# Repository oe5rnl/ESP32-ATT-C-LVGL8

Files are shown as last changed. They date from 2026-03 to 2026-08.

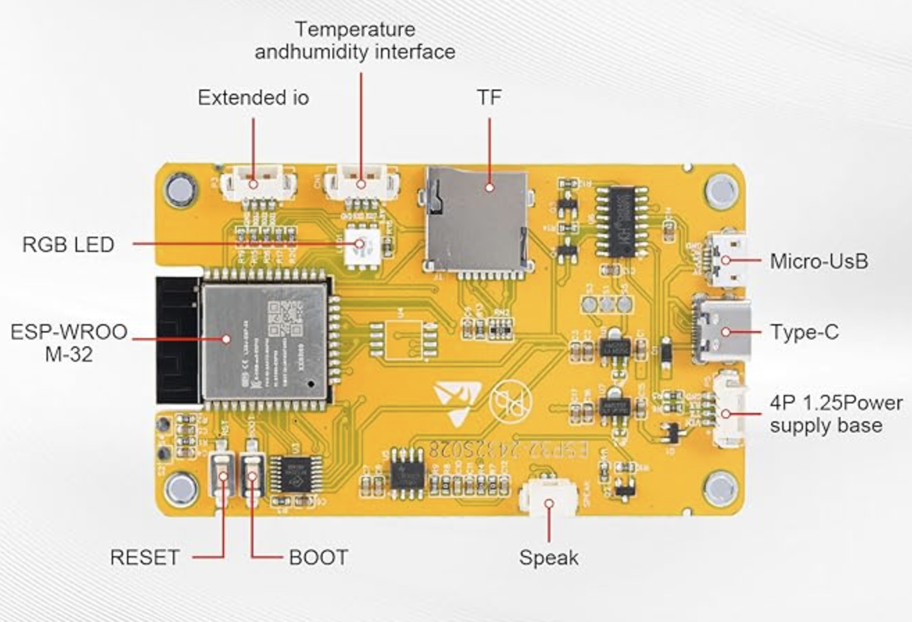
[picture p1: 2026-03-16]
esp32/docu/esp32-display/2-Specification/Board-hinten.png

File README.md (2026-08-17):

# Attenuator Controller

Das Projekt realisiert einen Controller für RF-Attenuators (HF-Dämpfungsglieder).

Es besteht aus einer Basisplatine und den optionalen Bendienelementen:  
* Ein ESP32 CYD Touch-Display  
* Ein 2.8" OLED Display  
* Einen Drehgeber mit Druckschalter  

Der Betrieb kann in folgenden Varianten erfolgen. Basisplatine **und**:  
* Nur ESP Touch Display
* OLED Display und Drehgeber
* ESP Touch Display und oder/und OLED sowie oder/und Drehgeber 

### Firmware installieren (ohne Installation)

Für Endnutzer gibt es im Ordner [install/](install/) einen Offline-Flasher, der
ohne PlatformIO oder Python auskommt — es wird nur ein mitgeliefertes Programm
aufgerufen. Details siehe [install/README.md](install/README.md).

- **ESP32:** Board per USB anstecken und `flash-esp32.sh` (Linux) bzw.
  `flash-esp32.bat` (Windows) ausführen. Der serielle Port wird automatisch
  erkannt; das eigenständige `esptool` ist bereits enthalten.
- **Pico:** **BOOTSEL** gedrückt halten, einstecken und `firmware/firmware.uf2`
  auf das Laufwerk `RPI-RP2` kopieren — ganz ohne Zusatzprogramm.

> **Hinweis:** Die auslieferbaren Firmware-Dateien werden vom Entwickler einmalig
> per [install/export.sh](install/export.sh) erzeugt (baut ESP32 + Pico und legt
> `firmware-merged.bin` sowie `firmware.uf2` in `install/firmware/` ab).

---

## Systemübersicht

ESP32 CYD (Touch-Display 320×240, WebGUI via WiFi, LVGL 8 UI) kommuniziert über
UART (115200 Baud) mit dem Raspberry Pi Pico (Drehgeber, SSD1306 OLED). Beide
steuern gemeinsam die Attenuator-Relais.

Verdrahtung

Der am häufigsten Abzutreffende Attenuatos ist die 135dB Variante.  
Siehe dazu zur Verkabelung ATT_135db.md  
Test der EinzelRelais mit dem Testmenü am Display und auf der Webseite.

### ESP32 — Touch-Controller

LVGL-8-Steuerungsoberfläche auf ESP32 CYD (Cheap Yellow Display):

- 2.8" Touch-Display ILI9341 (320×240), Variante CYD2USB mit ST7789
- WLAN: AP-Modus und Client-Modus gleichzeitig
- WebGUI mit identischer Funktion wie das Touch-Display
- NVS-Persistenz (Wert, Presets, WiFi-Modus, Set-Modus)
- FreeRTOS Dual-Core: LVGL/UI auf Core 1, WebSocket/WiFi auf Core 0
- Kommunikation mit dem Pico über UART0

### Pico — Relais-/Drehgeber-Controller

Raspberry Pi Pico als Attenuator-Controller:

- Drehgeber zur Auswahl und Aktivierung von Dämpfungswerten
- Optionales SSD1306 OLED-Display (I2C)
- Automatische Attenuator-Erkennung über ADC (Spannungsteiler an GP26 / ADC0)
- Bis zu 8 bistabile Relais (H-Brücke oder Einzel-Pin)
- Serielle Steuerung über UART vom ESP32

---

## Unterstützte Attenuatoren

Quelle: [pico/src/Attenuator.cpp](pico/src/Attenuator.cpp),
[pico/src/att_types.h](pico/src/att_types.h) und die jeweiligen `att_*`-Klassen.

| Typ | Max. dB | Schritte | Relay-Modus | Status im Code |
|-----|---:|---:|---|---|
| R&S 26.5 GHz | 110 dB | 10 dB | Static (Einzelpin) | implementiert (`Att26GHz`) |
| R&S RS-135 dB | 135 dB | 5 dB | Bridge (H-Brücke) | implementiert (`Att135dB`) |
| RS-141 dB | (variable Pads) | — | Bridge (H-Brücke) | implementiert (`Att141dB`) |
| Typ B | — | — | — | **nicht** implementiert (`AttB` → „NOT IMPLEMENTED") |

### Automatische Erkennung über ADC (GP26 / ADC0)

**Maßgeblich ist der Code** in [pico/src/main.cpp](pico/src/main.cpp) (`getAttenuator()`):

| Spannung (v) | Erkannter Attenuator |
|---|---|
| 0.0 V ≤ v < 0.7 V | RS-141 dB |
| 0.9 V ≤ v < 1.5 V | 26.5 GHz |
| 1.7 V ≤ v < 2.3 V | Typ B |
| 2.4 V ≤ v ≤ 3.3 V | RS-135 dB |
| außerhalb aller Fenster | **NOT IMPLEMENTED** — kein Attenuator, kein GPIO wird gesetzt |

> **Hinweis:** Die alten READMEs und der Kommentar in
> [pico/src/att_types.h](pico/src/att_types.h) nennen eine andere Zuordnung
> (0.0–0.8 V → 26.5 GHz usw.). Diese stimmt **nicht** mit dem aktuellen Code
> überein. Ungültige Spannungen (Lücken 0.7–0.9 / 1.5–1.7 / 2.3–2.4 V sowie alles
> außerhalb) liefern `getAttenuator()` = `-1`; `create_attenuator()` gibt dann
> `nullptr` zurück, es wird **kein GPIO** aktiviert und das Display zeigt
> „NOT IMPLEMENTED".

### Widerstände für den Spannungsteiler

R10 nach 3,3 V, R11 nach GND (an Pico ADC):

```
 3,3V
  |
 R10
  |---- Pico ADC (GP26)
  |
 R11
  |
 GND
```

| Attenuator | R10 | R11 |
|---|-----|-----|
| 26.5 GHz | offen | offen |
| RS-141 dB | 3k3 | 4k7 |
| Typ B | 4k7 | 3k3 |
| RS-135 dB | 0 Ohm | offen |

> **ACHTUNG:** Niemals zwei 0-Ohm-Widerstände einbauen — das kurzschließt den
> 3,3-V-Ausgang des Pico.
>
> **ACHTUNG:** Vor dem Verbinden des Attenuators mit der Steuerplatine am Display
> prüfen, ob der gewünschte Attenuator angezeigt wird. Wird `ATTENUATOR_26_5GHz`
> eingestellt, aber ein Attenuator mit H-Brücken-Ansteuerung verwendet, kann es
> zur Zerstörung der Relais führen.

---

## Hardware

### Pico — GPIO-Belegung

| Pin | GPIO | Funktion |
|-----|---|---|
| 1  | GP0  | TX → ESP32 (Serial1) |
| 2  | GP1  | RX ← ESP32 (Serial1) |
| 4  | GP2  | Relais 1a |
| 5  | GP3  | Relais 1b |
| 6  | GP4  | I2C SDA (Display) |
| 7  | GP5  | I2C SCL (Display) |
| 9  | GP6  | Relais 2a |
| 10 | GP7  | Relais 2b |
| 11 | GP8  | Relais 3a |
| 12 | GP9  | Relais 3b |
| 14 | GP10 | Relais 4a |
| 15 | GP11 | Relais 4b |
| 16 | GP12 | Relais 5a |
| 17 | GP13 | Relais 5b |
| 19 | GP14 | Relais 6a |
| 20 | GP15 | Relais 6b |
| 21 | GP16 | Relais 7a |
| 22 | GP17 | Relais 7a |
| 24 | GP18 | Relais 8a |
| 25 | GP19 | Encoder SW |
| 26 | GP20 | Encoder DT (B) | 
| 27 | GP21 | Encoder CLK (A) |
| 29 | GP22 | Relais 8b |
| 31 | GP26 | ADC0 — Attenuator-Erkennung |
| 32 | GP27 | Relais 9a |
| 34 | GP28 | Relais 9b |

#### Relais-Mapping RS-135 dB (bistabil, ON/OFF-Pin-Paare)

Quelle: [pico/src/att_135db.h](pico/src/att_135db.h) / [.cpp](pico/src/att_135db.cpp).

| Relais | ON-Pin | OFF-Pin | tatsächlicher Pad-Wert |
|---|---|---|---|
| U1 (40bB A) | GP3 | GP2 | 40 dB |
| U2 (20dB A) | GP7 | GP6 | 20 dB |
| U3 (5 dB) | GP9 | GP8 | 5 dB |
| U4 (20dB B) | GP11 | GP10 | 20 dB |
| U5 (10 dB) | GP13 | GP12 | 10 dB |
| U6 (40dB B) | GP15 | GP14 | 40 dB |
| U7 (RF) | GP17 | GP16 | RF ON/OFF |

#### Relais-Mapping 26.5 GHz (Static, HIGH = aktiv)

Quelle: [pico/src/att_26ghz.h](pico/src/att_26ghz.h).

| Pad | GPIO | Pin |
|-----|---|-----|
| 10 dB | GP10 | 14 |
| 20 dB | GP11 | 15 |
| 40 dB (A) | GP12 | 16 |
| 40 dB (B) | GP13 | 17 |

---

## WiFi-Konfiguration

### WiFi-Credentials einstellen

Erstelle `esp32/src/wifi_credentials.h` mit deinen WLAN-Zugangsdaten (Vorlage:
[esp32/src/wifi_credentials.h.example](esp32/src/wifi_credentials.h.example)):

Der AP ist unabhängig von der Datei stets erreichbar. Die Client-Anbindung ans Heimnetz kann man jederzeit zur Laufzeit über die WebGUII (WLAN-Suche → Verbinden) oder das Display setzen — die Werte landen im NVS. wifi_credentials.h ist nur praktisch, wenn man die Zugangsdaten schon beim Kompilieren fest hinterlegen will (z. B. damit sich das Gerät ohne manuelle Ersteinrichtung direkt verbindet).

```cpp
#pragma once
#define WIFI_SSID     "DeinSSID"
#define WIFI_PASSWORD "DeinPasswort"
```

Diese Datei ist in [.gitignore](.gitignore) und wird nicht committet.

### WiFi-Modi

Quelle: [esp32/src/webserver.h](esp32/src/webserver.h) (`apply_wifi_mode()`).

Es gibt genau **zwei** Modi; jeder von 0 verschiedene Wert wird intern auf `2`
gesetzt. Die Einstellung wird im NVS (`wmode`) gespeichert.

- **Modus 0 (Aus):** WiFi vollständig deaktiviert (`WIFI_OFF`), Webserver und AP
  werden gestoppt, mDNS beendet.
- **Modus 2 (AP + Client):** Der Access Point ist **immer** aktiv. Ein
  Client (STA) wird zusätzlich nur gestartet, wenn gültige Client-Zugangsdaten
  vorliegen — andernfalls läuft das Gerät im AP-only-Betrieb.
  - AP-SSID: `ESP32-ATT`
  - AP-Passwort: `12345678` (Standardwert — bitte ändern)
  - AP-IP: `192.168.4.1`
  - Client-Zugangsdaten stammen aus dem NVS (`wifi_ssid` / `wifi_pass`),
    vorbelegt aus [esp32/src/wifi_credentials.h](esp32/src/wifi_credentials.h);
    zur Laufzeit über das Display-Menü (**Menu → WLAN**) bzw. die WLAN-Suche der
    WebGUI setzbar.
  - Die Client-Verbindung erfolgt nicht blockierend; nach Timeout (ca. 20 s) oder
    bei Fehler fällt das Gerät automatisch auf AP-only zurück.
  - mDNS (`esp32-att.local`) wird erst nach erfolgreicher Client-Verbindung
    aktiviert.

### WebGUI

Nach dem Start erreichbar unter:
- **AP-Modus:** `http://192.168.4.1`
- **Client-Modus:** `http://esp32-att.local` (oder die angezeigte IP)

---

## Quick Start

### ESP32 flashen
```bash
cd esp32
./upload.sh
# oder manuell:
~/.platformio/penv/bin/pio run -t upload
~/.platformio/penv/bin/pio device monitor
# CYD2USB-Variante (ST7789):
~/.platformio/penv/bin/pio run -e cyd2usb -t upload
```

### Pico flashen
```bash
cd pico
./upload_main.sh
# oder manuell:
~/.platformio/penv/bin/pio run -t upload
~/.platformio/penv/bin/pio device monitor
```

> **Tipp:** Falls `pio: command not found` erscheint, den vollen Pfad
> `~/.platformio/penv/bin/pio` verwenden oder PlatformIO global installieren.

**Voraussetzungen:** [PlatformIO](https://platformio.org/) (CLI oder VS-Code-Extension).

### Tools einrichten

1. **Repository holen**
   ```bash
   git clone <REPO-URL>
   cd ESP32-ATT-C-LVGL8
   ```

2. **PlatformIO installieren** — eine der beiden Varianten:
   - **VS Code + Extension (empfohlen):** [VS Code](https://code.visualstudio.com/)
     installieren, dann die Extension **PlatformIO IDE** hinzufügen. Build/Upload
     erfolgen über die PlatformIO-Toolbar.
   - **CLI (Kommandozeile):**
     ```bash
     python3 -m pip install --user platformio
     # oder das offizielle Installskript:
     # curl -fsSL https://raw.githubusercontent.com/platformio/platformio-core-installer/master/get-platformio.py | python3
     ```
     Danach steht `pio` unter `~/.platformio/penv/bin/pio` zur Verfügung
     (ggf. in den `PATH` aufnehmen).

3. **Toolchains & Bibliotheken** — werden beim ersten `pio run` automatisch
   geladen (Platforms `espressif32` und `raspberrypi`, Frameworks und alle
   `lib_deps` aus den jeweiligen [platformio.ini](esp32/platformio.ini)).
   Eine manuelle Installation ist nicht nötig.

4. **Serielle Rechte (Linux):** Für Upload/Monitor den eigenen Benutzer zur
   Gruppe `dialout` hinzufügen und neu anmelden:
   ```bash
   sudo usermod -aG dialout $USER
   ```

5. **WLAN-Zugangsdaten (optional):** Nur nötig, wenn die Client-Zugangsdaten
   bereits beim Kompilieren fest hinterlegt werden sollen — siehe Abschnitt
   „WiFi-Credentials einstellen". Ohne diese Datei ist der Access Point trotzdem
   erreichbar; die Client-Anbindung lässt sich zur Laufzeit über WebGUI/Display
   setzen.

---

## Serielles Kommunikationsprotokoll (UART, 115200 Baud)

Alle Nachrichten sind ASCII-Zeilen, abgeschlossen mit `\n`.

### Pico → ESP32

**Startup-Info** (einmalig nach Pico-Reset):

| Befehl | Beschreibung |
|---|---|
| `RELAYS:<n>` | Anzahl der Relais |
| `ATTNAME:<name>` | Attenuator-Name |
| `STEP:<n>` | Schrittweite in dB |
| `MAXDB:<n>` | Maximalwert in dB |
| `RELMODE:<n>` | Relay-Modus: `0`=Bridge, `1`=Static |
| `RFSWITCH:<n>` | RF-Schalter vorhanden: `0`/`1` |
| `PICOVER:<ver>` | Pico-Firmware-Version |

**Laufzeit:**

| Befehl | Beschreibung |
|---|---|
| `<n>dB` | Aktueller Dämpfungswert (Display-Sync) |
| `SEL<n>` | Ausgewählte Stelle: `0`=Hunderter, `1`=Zehner, `2`=Einer |
| `SETMODE:<n>` | Set-Modus: `0`=Direct, `1`=Time, `2`=Button |
| `RF:<n>` | RF-Schalter-Zustand: `0`/`1` |
| `TESTSTATE:<i>,<s>` | Test: Relais-Index `i`, Zustand `s` (`0`/`1`) |
| `SETOK` | Pico hat im Set-Button-Modus angewendet |

### ESP32 → Pico

| Befehl | Beschreibung |
|---|---|
| `<n>dB` | Dämpfung Display-Sync (kein Schalten) |
| `SET:<n>dB` | Dämpfung sofort schalten (Relais) |
| `TIMED:<n>dB` | Zeitgesteuert schalten |
| `SEL<n>` | Aktive Stelle ändern |
| `SETMODE:<n>` | Set-Modus umschalten |
| `RF:<n>` | RF-Schalter setzen: `0`/`1` |
| `TEST:START` | Relay-Test starten |
| `TEST:SEL:<i>` | Test-Relais `i` auswählen |
| `TEST:ACTION` | Test: Puls/Toggle am gewählten Relais |
| `TEST:END` | Test beenden |

---

## Implementierungsdetails ESP32

| Core | Aufgaben |
|---|---|
| **Core 0** | WiFi-Stack, AsyncTCP, ESPAsyncWebServer, WebSocket-Callbacks |
| **Core 1** | `setup()` / `loop()`, LVGL `lv_timer_handler()`, UART-Empfang |

Kommunikation zwischen den Cores über FreeRTOS-Queue (`xQueueSend` / `xQueueReceive`).

---

## Projektstruktur

```
ESP32-ATT-C-LVGL8/
├── shared/
│   └── version.h               # Versionsnummern ESP32 + Pico (0.51)
├── esp32/
│   ├── platformio.ini          # PlatformIO + TFT_eSPI Build-Flags
│   ├── lv_conf.h               # LVGL-8-Konfiguration
│   └── src/
│       ├── main.cpp            # LVGL UI, UART-Kommunikation
│       ├── webserver.h         # AsyncWebServer, WebSocket, HTML
│       ├── wifi_credentials.h  # WLAN-Zugangsdaten (nicht im Repo)
│       └── lv_font_digits_72.c # Custom 72 px Ziffern-Font
├── pico/
│   └── src/
│       ├── main.cpp            # Hauptprogramm, UART, Encoder, ADC-Erkennung
│       ├── Attenuator.h/.cpp   # Abstrakte Basisklasse + Factory
│       ├── att_26ghz.h/.cpp    # R&S 26.5 GHz (Static, 110 dB / 10 dB)
│       ├── att_135db.h/.cpp    # R&S 135 dB (Bridge, 135 dB / 5 dB)
│       ├── att_141db.h/.cpp    # RS-141 dB (Bridge)
│       ├── att_b.h/.cpp        # Typ B (nicht implementiert)
│       ├── att_types.h         # Typ-Konstanten + ADC-Grenzwerte (Kommentar veraltet)
│       ├── test.h/.cpp         # Relay-Testmodus
│       ├── SSD1306.h/.cpp      # OLED-Display-Treiber
│       ├── big_digits.h        # Große Ziffern für OLED
│       ├── font.h              # OLED-Font
│       └── toggle_gpio10_13.cpp # Standalone-GPIO-Testhilfe
├── Schaltung/                  # KiCad Schaltplan + PCB
├── install/                    # Offline-Flasher (esptool + Skripte, ohne Installation)
└── docs/                       # Zusätzliche Dokumentation
```

---

## Lizenz

MIT — siehe [LICENSE](LICENSE).

Ausnahme: Der Ordner [esp32/docu/esp32-display/](esp32/docu/esp32-display/)
enthält Hersteller-Dokumentation (Sunton) und ist **nicht** von der MIT-Lizenz
abgedeckt.

Build by OE5RNL & OE5NVL & Chatgpt & Claude

### Haftungsausschluss

Diese Hard- und Software wird „wie besehen" ohne jegliche Gewährleistung
bereitgestellt — weder ausdrücklich noch stillschweigend, insbesondere keine
Gewährleistung der Marktgängigkeit oder Eignung für einen bestimmten Zweck.
Die Nutzung erfolgt auf eigene Gefahr. Die Autoren übernehmen keine Haftung für
Schäden jeglicher Art (z. B. an Attenuatoren, Relais, Messgeräten oder sonstiger
Ausrüstung), die aus dem Aufbau, dem Betrieb oder der Nutzung dieses Projekts
entstehen.

Insbesondere kann eine falsche Attenuator-Erkennung oder fehlerhafte Verdrahtung
zur Zerstörung der Relais oder des angeschlossenen Dämpfungsglieds führen (siehe
Warnhinweise im Abschnitt „Widerstände für den Spannungsteiler"). Vor dem
Anschluss stets prüfen, ob der korrekte Attenuator angezeigt wird.

## Basiert auf

[ESP32-Cheap-Yellow-Display](https://github.com/witnessmenow/ESP32-Cheap-Yellow-Display)
— LVGL8-Beispiel.

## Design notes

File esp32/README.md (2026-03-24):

# ESP32 - 26.5 GHz Attenuator Controller

LVGL 8 Steuerungsoberfläche für ESP32 CYD (Cheap Yellow Display) mit Touch-Display und WebGUI.

## Features

- **3-Tab-Menü** (Main, Defaults, Config) mit Tab-Leiste am unteren Rand
- **Main-Tab:** 3-stellige Ziffernanzeige (72px Custom Font), einzeln anwählbar per Touch mit Unterstrich-Cursor. UP/Down/Set-Buttons ändern die ausgewählte Stelle
- **Defaults-Tab:** 6 vordefinierte dB-Werte als Buttons (2 Reihen × 3). Kurzer Klick übernimmt den Wert, langer Klick öffnet ein Nummernfeld zum Editieren
- **Config-Tab:** Autoenter-Switch (ein/aus), WLAN-Modus (Aus / AP / Client)
- **Ziffernbegrenzung:** Maximalwert und aktivierbare Stellen über `#define` konfigurierbar (`DIGIT_MAX_VAL`, `DIGIT_MAX_0/1/2`)
- **Persistente Speicherung:** Ziffernwert, Default-Button-Werte, Autoenter und WiFi-Modus werden im ESP32 NVS gespeichert und überleben Stromausfall/Neustart
- **Webinterface:** Steuerung über Browser (WiFi AP oder Client-Modus)
- **Set-Button:** Wird nur angezeigt wenn Autoenter ausgeschaltet ist

## Hardware

- **Board:** ESP32-2432S028 (Cheap Yellow Display / CYD)
- **Display:** ILI9341, 320×240, RGB565, SPI
- **Touch:** XPT2046 auf separatem VSPI-Bus
- **Variante CYD2USB:** ST7789-Treiber (Environment `cyd2usb`)
- **Attenuator GPIOs** (active LOW):
  - GPIO 4: 10 dB Pad
  - GPIO 16: 20 dB Pad
  - GPIO 17: 40 dB Pad A
  - GPIO 35: 40 dB Pad B
- **UART für Pico** (am P3 Stecker):
  - GPIO 21: TX → Pico GP1 (Serial1 RX)
  - GPIO 22: RX ← Pico GP0 (Serial1 TX)

## Voraussetzungen

- [PlatformIO](https://platformio.org/) (CLI oder VS Code Extension)
- ESP32-2432S028 Board (CYD)

## Build & Flash

```bash
# Standard CYD (ILI9341)
~/.platformio/penv/bin/pio run -t upload

# CYD2USB Variante (ST7789)
~/.platformio/penv/bin/pio run -e cyd2usb -t upload

# Seriellen Monitor öffnen
~/.platformio/penv/bin/pio device monitor  -p /dev/ttyUSB0
```

> **Tipp:** Falls `pio: command not found` erscheint, verwende den vollen Pfad `~/.platformio/penv/bin/pio` oder installiere PlatformIO global.

## WiFi-Konfiguration

### WiFi-Credentials einstellen

Erstelle `src/wifi_credentials.h` mit deinen WLAN-Zugangsdaten:

```cpp
#pragma once
#define WIFI_SSID "DeinSSID"
#define WIFI_PASSWORD "DeinPasswort"
```

Diese Datei ist in `.gitignore` und wird nicht committed.

### WiFi-Modi

- **Modus 0 (Aus):** WiFi deaktiviert
- **Modus 1 (AP):** Access Point Modus
  - SSID: `ESP32-ATT`
  - Passwort: `12345678`
  - IP: `192.168.4.1`
- **Modus 2 (Client):** Verbindet sich mit deinem WLAN
  - Läuft parallel zum AP für durchgehende Erreichbarkeit
  - Verwendete Zugangsdaten: Aus Config-Tab oder `wifi_credentials.h`
  - mDNS: `esp32-att.local`

## WebGUI

Nach dem Start ist das WebInterface erreichbar unter:
- **AP-Modus:** http://192.168.4.1
- **Client-Modus:** http://esp32-att.local (oder die angezeigte IP)

Das WebGUI bietet die gleichen Funktionen wie das Touch-Display:
- Dämpfungswert einstellen (UP/DOWN oder direkte Eingabe)
- Default-Werte verwalten
- Auto-Set ein/aus
- WLAN-Netzwerke scannen und verbinden (im AP-Modus)

## Projektstruktur

```
esp32/
├── platformio.ini          # PlatformIO Konfiguration mit TFT_eSPI Build-Flags
├── lv_conf.h               # LVGL 8 Konfiguration (Montserrat 24/48 aktiviert)
├── src/
│   ├── main.cpp            # Hauptprogramm mit LVGL GUI
│   ├── webserver.h         # AsyncWebServer + WebSocket
│   ├── wifi_credentials.h  # WiFi-Zugangsdaten (git-ignored)
│   └── lv_font_digits_72.c # Custom 72px Ziffern-Font
└── README.md               # Diese Datei
```

## Anpassungen

### Maximalwerte ändern

In `src/main.cpp`:

```cpp
#define DIGIT_MAX_VAL  110   /* maximaler Gesamtwert in dB             */
#define DIGIT_MAX_0      1   /* Hunderter: 0 .. DIGIT_MAX_0           */
#define DIGIT_MAX_1      9   /* Zehner:    0 .. DIGIT_MAX_1           */
#define DIGIT_MAX_2      0   /* Einer:     0 = nicht wählbar (10er-Schritte) */
```

### Default-Werte ändern

In `src/main.cpp`:

```cpp
int32_t default_values[6] = {20, 40, 60, 10, 30, 50};
```

## Lizenz

Siehe [LICENSE](../LICENSE) im Root-Verzeichnis.

## Credits

Basiert auf dem LVGL8 Beispiel von [ESP32-Cheap-Yellow-Display](https://github.com/witnessmenow/ESP32-Cheap-Yellow-Display).

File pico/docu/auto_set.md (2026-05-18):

# Auto-Set Funktion

## Grundidee

Auto-Set steuert, ob eine Änderung des dB-Werts *sofort* an die Relais
weitergegeben wird oder erst nach einem expliziten Bestätigungsschritt.

---

## ESP32

**Zustand:** `bool autoset`  
Standard: `true`, persistent in NVS via `prefs.putBool("ae", autoset)`

### Auto-Set ON
- Jeder Druck auf UP/DOWN (`btn_up_cb` / `btn_down_cb`) ruft sofort
  `apply_attenuation()` auf → Relais schalten unmittelbar
- Der „SET"-Button ist **versteckt** (`LV_OBJ_FLAG_HIDDEN`)
- Digit-Klick im Haupttab löst ebenfalls sofort `apply_attenuation()` aus

### Auto-Set OFF
- UP/DOWN ändert nur den angezeigten Wert, die Relais schalten **nicht**
- Der „SET"-Button wird **sichtbar** – erst sein Druck ruft
  `apply_attenuation_set()` auf
- Der Wert kann unverbindlich eingestellt und dann per Tastendruck übernommen werden

### Quellen für Zustandsänderungen

| Auslöser | Reaktion |
|---|---|
| Toggle-Switch im Config-Tab (LVGL)| Speichert in NVS, sendet `AUTO:ON/OFF` per Serial an Pico, WebSocket-Broadcast |
| Web-Interface (Browser) | `web_update_ae()` synchronisiert LVGL-Switch + Label + SET-Button, sendet `AUTO:ON/OFF` an Pico |
| Serial-Eingang vom Pico (`AUTO:ON/OFF`) | Aktualisiert `autoset`, NVS, LVGL-Switch, Label, SET-Button |

---

## Pico

**Zustand:** `bool auto_set_mode`  
Standard: `true`

### Auto-Set ON
- Wenn der ESP32 einen dB-Wert schickt (`"XXXdB"`), ruft
  `apply_attenuation_from_esp_db()` auch `apply_relays()` auf → Relais
  schalten sofort mit
- OLED zeigt unten: `AUTO-SET: ON`

### Auto-Set OFF
- `apply_attenuation_from_esp_db()` aktualisiert nur Display und internen
  Zustand, ruft **kein** `apply_relays()` auf
- OLED zeigt unten: `AUTO-SET: OFF`
- Ein **Encoder-Einzelklick** übernimmt den angezeigten Wert manuell auf die
  Relais und sendet ihn zurück an den ESP32

### Quellen für Zustandsänderungen

| Auslöser | Reaktion |
|---|---|
| Serial vom ESP32 (`AUTO:ON/OFF`)  | Setzt `auto_set_mode`, aktualisiert OLED |
| Beim Start | Sendet aktuellen Zustand per `sync_state_to_esp32()` → ESP32 übernimmt ihn |

---

## Synchronisation zwischen ESP32 und Pico

```
ESP32  ──── AUTO:ON / AUTO:OFF ────►  Pico   (Serial1, 115200 Baud)
Pico   ──── AUTO:ON / AUTO:OFF ────►  ESP32  (beim Booten via sync_state_to_esp32)
```

Der Zustand wird in **beide Richtungen** synchronisiert.  
Der ESP32 ist Master für Änderungen aus UI und Web-Interface.  
Der Pico schickt seinen persistierten Zustand beim Start.  
**Letzter Schreiber gewinnt.**

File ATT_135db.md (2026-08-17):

# 135 dB Attenuator – Schaltplan

```
                                                 ╔═════════════════════════
                                                 ║
   135dB Attenuator                              ║   Controller Board
                                                 ║
╔════════════════════╗                           ║
║                    ║                           ║
║                ┌──────────────────────────────────── B1 U1out1 
║   O    40dB    O   ║                           ║
║   └───────────────────────────────────────────────── B1 U1out2
║                    ║                           ║
║                    ║                           ║
║                ┌──────────────────────────────────── B2 U2out1 
║   O    20dB    O   ║                           ║
║   └───────────────────────────────────────────────── B2 U2out2
║                    ║                           ║
║                    ║                           ║
║                ┌──────────────────────────────────── B3 U3out1
║   O     5dB    O   ║                           ║
║   └───────────────────────────────────────────────── B3 U3out2
║                    ║                           ║
║                    ║                           ║
║                ┌──────────────────────────────────── B4 U4out1
║   O    20dB    O   ║                           ║
║   └───────────────────────────────────────────────── B4 U4out2
║                    ║                           ║
║                    ║                           ║
║                ┌──────────────────────────────────── B5 U5out1 
║   O    10dB    O   ║                           ║
║   └───────────────────────────────────────────────── B5 U5out2
║                    ║                           ║
║                    ║                           ║
║                ┌──────────────────────────────────── B6 U6out1 
║     O  40dB    O   ║                           ║
║   └───────────────────────────────────────────────── B6 U6out2
║                    ║                           ║
║                    ║                           ║
║                ┌──────────────────────────────────── B7 U7out1
║   O    RF-SW   O   ║                           ║
║   └───────────────────────────────────────────────── B7 U7out2
║                    ║                           ║
║                    ║                           ║
║                    ║                           ║     B8 U8out1
║                    ║                           ║
║                    ║                           ║     B8 U8out2
║                    ║                           ║
║                    ║                           ║
║                    ║                           ║     B9 U9out1
║                    ║                           ║
╚════════════════════╝                           ║     B9 U9out2
                                                 ║
                                                 ║
                                                 ║
                                                 ╚═════════════════════════
```
Das ist die am häfigsten anzutreffende Version des Abschwächers !!!

Es gibt zwei Versionen von diesem Schater.  
Die Lage der dB Schalter ist bei beiden gleich.  

Beide haben einen RF ON/OFF Schalter.  
Bei der Version A befinden sich die RF-SW Pins direkt neben dem dB Schaltern.  
Bei der Version B besteht ein Abstand zwischen des dB Schaltern und dem RF-Switch.  

Von der Funktionalität sind beide Schalter gleich, nur
der Frequenzgereich ist unterschiedlich.

Der Schalter mit dem Abstand hat Dioden zur Erkennung der Rückleistung  
eigebaut. Diese begrenzen den Frequenzbereich.

Die Funktion der Demodulator-Dioden wird vom Controller nicht unterstützt!

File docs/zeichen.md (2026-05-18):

---

## Box-Drawing Characters – Referenz

### Einfache Linie (Single)
```
┌─────────────────────┐
│  Inhalt             │
├─────────────────────┤
│  Zeile 2            │
└─────────────────────┘
```

### Doppelte Linie (Double)
```
╔═════════════════════╗
║  Inhalt             ║
╠═════════════════════╣
║  Zeile 2            ║
╚═════════════════════╝
```

### Gemischt – Horizontal doppelt / Vertikal einfach
```
╒═════════════════════╕
│  Inhalt             │
╞═════════════════════╡
│  Zeile 2            │
╘═════════════════════╛
```

### Gemischt – Horizontal einfach / Vertikal doppelt
```
╓─────────────────────╖
║  Inhalt             ║
╟─────────────────────╢
║  Zeile 2            ║
╙─────────────────────╜
```

### Zeichen-Übersicht

| Funktion | Einfach | Doppelt |
|---|:---:|:---:|
| Ecke oben links | ┌ | ╔ |
| Ecke oben rechts  | ┐ | ╗ |
| Ecke unten links  | └ | ╚ |
| Ecke unten rechts | ┘ | ╝ |
| Horizontal | ─ | ═ |
| Vertikal | │ | ║ |
| T links | ├ | ╠ |
| T rechts | ┤ | ╣ |
| T oben | ┬ | ╦ |
| T unten | ┴ | ╩ |
| Kreuz | ┼ | ╬ |

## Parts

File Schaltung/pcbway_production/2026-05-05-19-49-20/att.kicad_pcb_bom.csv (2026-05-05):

Designator | Quantity | Value | Footprint | Package | MPN | DNP | Mount_Type | Description | KiLib_Generator
A1 | 1 | RaspberryPi_Pico | RaspberryPi_Pico_SMD |  |  |  | smt | Versatile and inexpensive microcontroller module (with full pinout for test point and debug connections) powered by RP2040 dual-core Arm Cortex-M0+ processor up to 133 MHz, 264kB SRAM, 2MB QSPI flash; also supports Raspberry Pi Pico 2
C1, C11, C12, C13, C2, C3, C4, C5, C6, C7, C8, C9 | 12 | 100nF | C_0805_2012Metric |  |  |  | smt | Unpolarized capacitor | SMD_2terminal_chip_molded
C10 | 1 | 47uF 50V | CP_Radial_D8.0mm_P5.00mm |  |  |  | tht | Polarized capacitor | capacitor/THT/other
C21 | 1 | 47uF 50V | CP_Elec_6.3x5.2 |  |  |  | smt | Polarized capacitor | capacitor/SMD/elec_round_polarized
J1 | 1 | 12V Power supply | TerminalBlock_MetzConnect_Type055_RT01502HDWU_1x02_P5.00mm_Horizontal |  |  |  | tht | Generic screw terminal, single row, 01x02, script generated (kicad-library-utils/schlib/autogen/connector/) | terminal_block/Metz_Connect
J2 | 1 | R&S Attenuator 26.5 GHz | PinHeader_2x05_P2.54mm_Vertical |  |  |  | tht | Generic connector, double row, 02x05, counter clockwise pin numbering scheme (similar to DIP package numbering), script generated (kicad-library-utils/schlib/autogen/connector/) | connector/pin_header_socket
J3 | 1 | dB Drehgeber | PinHeader_1x05_P2.54mm_Vertical |  |  |  | tht | Generic connector, single row, 01x05, script generated | connector/pin_header_socket
J4 | 1 | ESP-Controller | PinHeader_1x04_P2.54mm_Vertical |  |  |  | tht | Generic connector, single row, 01x04, script generated | connector/pin_header_socket
J5 | 1 | xxx | PinHeader_2x02_P2.54mm_Vertical |  |  |  | tht | Generic connector, double row, 02x02, counter clockwise pin numbering scheme (similar to DIP package numbering), script generated (kicad-library-utils/schlib/autogen/connector/) | connector/pin_header_socket
J6 | 1 | Display | PinHeader_1x04_P2.54mm_Vertical |  |  |  | tht | Generic connector, single row, 01x04, script generated | connector/pin_header_socket
R1, R10, R11, R2, R4, R5, R6, R7, R8, R9 | 10 | 15k | R_0805_2012Metric |  |  |  | smt | Resistor | SMD_2terminal_chip_molded
R3 | 1 | 15K | R_0805_2012Metric |  |  |  | smt | Resistor | SMD_2terminal_chip_molded
U1, U2, U3, U4, U5, U6, U7, U8, U9 | 9 | DRV8871DDA | Texas_HTSOP-8-1EP_3.9x4.9mm_P1.27mm_EP2.95x4.9mm_Mask2.4x3.1mm_ThermalVias |  |  |  | smt | Brushed DC Motor Driver, PWM Control, 45V, 3.6A, Current limiting, HTSOP-8
U10 | 1 | ~ | DC-DC_12_5 |  |  |  | smt
U11 | 1 | ~ | ttl_converter |  |  |  | smt
U12 | 1 | ~ | DC-DC_12_24 |  |  |  | smt
U13 | 1 | ~ | SIL_18 |  |  |  | smt

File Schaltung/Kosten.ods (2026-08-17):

 | Attenuator Controller
Value | Qty | Preis | Summe | Preis+MWST | Reference | Mouser-Nr.
RaspberryPi_Pico | 1 | 3,44 | 3,44 | 4,13 | A1 | 358-SC0915
100nF | 12 | 0,03 | 0,35 | 0,42 | C1, C2, C3, C4, C5, C6, C7, C8, C9, C11, C12, C13 | 80-C0805C104M3RAC
47uF 50V | 1 | 0,35 | 0,35 | 0,42 | C10 | 232-50NXA47MEFC8X115
47uF 50V | 1 | 0,20 | 0,20 | 0,24 | C21 | 667-EEU-FC1H470H
15k | 11 | 0,01 | 0,12 | 0,15 | R1, R3, R2, R4, R5, R6, R7, R8, R9, R10, R11 | 652-CR0805FX-1502ELF
DRV8871DDA | 7 | 1,61 | 11,27 | 13,52 | U1, U2, U3, U4, U5, U6, U7 | 595-DRV8871DDAR
DCDC12 auf 5 | 1 | 1,49 | 1,49 | 1,49 | U10
DCDC12 auf 24 | 1 | 2,35 | 2,35 | 2,35 | U12
Leiterplatte | 1 | 3,00 | 3,00 | 3,00
Display | 1 | 17,00 | 17,00 | 17,00
Display 2 | 1 | 3,56 | 3,56 | 3,56
Drehregler | 1 | 2,14 | 2,14 | 2,14
Summe |  |  | 45,28 | 48,42

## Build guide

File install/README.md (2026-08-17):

# Firmware-Installer (offline, ohne Installation)

Dieses Verzeichnis flasht die Firmware auf **ESP32** und **Raspberry Pi Pico** —
komplett offline, ohne dass der Nutzer Software installieren muss. Es wird nur
ein mitgeliefertes Programm **aufgerufen**.

```
install/
├── flash-esp32.sh      # ESP32 flashen (Linux)
├── flash-esp32.bat     # ESP32 flashen (Windows)
├── esptool/            # eigenstaendige esptool-Binaries (esptool + esptool.exe, v5.3.1)
├── firmware/           # firmware-merged.bin (ESP32) + firmware.uf2 (Pico)
└── export.sh           # nur fuer Entwickler: baut + erzeugt die Firmware-Dateien
```

---

## ESP32 flashen

1. ESP32 (CYD) per USB anstecken.
2. **Linux:** im Terminal `./flash-esp32.sh` ausführen.
   **Windows:** `flash-esp32.bat` doppelklicken.
3. Warten bis „Fertig" erscheint — die Firmware ist geflasht.

Der serielle Port wird automatisch erkannt.

### Hinweise
- **Linux-Rechte:** Falls der Zugriff auf den USB-Port scheitert, den Benutzer
  einmalig zur Gruppe `dialout` hinzufügen und neu anmelden:
  `sudo usermod -aG dialout $USER` (alternativ das Skript mit `sudo` starten).
- **Windows-Treiber:** Die CYD-Boards nutzen einen **CH340**- oder **CP2102**-
  USB-Seriell-Chip. Falls Windows das Gerät nicht erkennt, den passenden Treiber
  installieren (WCH CH340 bzw. Silicon Labs CP210x).

---

## Pico flashen (kein Programm nötig)

1. **BOOTSEL**-Taste am Pico gedrückt halten und Pico per USB anstecken.
   Es erscheint ein Laufwerk namens **`RPI-RP2`**.
2. Die Datei `firmware/firmware.uf2` per Drag & Drop auf dieses Laufwerk kopieren.
3. Der Pico startet automatisch neu und ist fertig geflasht.

---

## Für den Entwickler: Firmware-Dateien erzeugen

`export.sh` baut beide Projekte mit PlatformIO und legt die auslieferbaren
Dateien in `firmware/` ab:

```bash
cd install
./export.sh
```

Ergebnis:
- `firmware/firmware-merged.bin` — eine einzige ESP32-Datei (Bootloader +
  Partitionen + App zusammengeführt).
- `firmware/firmware.uf2` — Pico-Firmware.

Die eigenständigen **esptool**-Binaries (`esptool` für Linux, `esptool.exe` für
Windows, v5.3.1) liegen bereits in `esptool/`. Aktualisieren lassen sie sich bei
Bedarf über die [Espressif-Releases](https://github.com/espressif/esptool/releases).

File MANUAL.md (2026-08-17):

# Benutzerhandbuch — Attenuator Controller

Bedienung des Dämpfungsglied-Controllers. Die Steuerung ist auf zwei Wegen
möglich, die jederzeit denselben Gerätezustand teilen (bidirektional per
WebSocket synchronisiert):

- **Touch-Display** — LVGL-Oberfläche direkt am ESP32.
- **Web-Oberfläche** — im Browser über WLAN erreichbar.

## Verkabelung

Verdrahtung

Der am häufigsten Abzutreffende Attenuatos ist die 135dB Variante.  
Siehe dazu zur Verkabelung ATT_135db.md  
Test der EinzelRelais mit dem Testmenü am Display und auf der Webseite.

---

## A) Touch-Display

Die Oberfläche gliedert sich in **drei Tabs** (Tab-Leiste am unteren Rand):
**Main**, **Presets** und **Menu**.

### Tab „Main" — Dämpfungswert einstellen

- **3-stellige Ziffernanzeige** (Hunderter | Zehner | Einer) in großer Schrift.
- Unter der aktiven Stelle steht ein **Unterstrich-Cursor**.
- Bedienelemente:
  - **UP** — erhöht die gewählte Stelle (Hunderter × 100, Zehner × 10).
  - **DOWN** — verringert die gewählte Stelle.
  - **Set** — überträgt den Wert an den Pico (nur im Modus *Set-Button* sichtbar,
    siehe unten). Wird **rot**, sobald der angezeigte Wert vom zuletzt gesetzten
    abweicht.
  - **RF-Schalter** — schaltet den HF-Zweig **ON (grün) / OFF (rot)**. Nur
    sichtbar, wenn das erkannte Dämpfungsglied einen RF-Schalter besitzt.
  - **Status-Label** — zeigt den aktiven Set-Modus: `SET-DIRECT`, `SET-TIME`
    oder `SET-BUTTON`.

**Wert ändern:**
- **Ziffer antippen** wählt die aktive Stelle aus (Cursor springt dorthin).
- **UP/DOWN gedrückt halten** wiederholt das Zählen automatisch.
- **Ziffer lang drücken** öffnet ein Zahlenfeld zur direkten Eingabe des
  Gesamtwerts.
- Über die serielle Verbindung vom Pico empfangene Werte aktualisieren die
  Anzeige automatisch.

### Tab „Presets" — Schnellzugriffe

- **9 Buttons** in einem 3×3-Raster, jeder mit einem hinterlegten dB-Wert
  beschriftet.
- Ein Button wird **rot** hervorgehoben, wenn sein Wert dem aktuellen entspricht.
- **Kurzer Klick** — wendet den Preset-Wert sofort an.
- **Langer Klick (ca. 600 ms)** — öffnet ein Zahlenfeld zum Bearbeiten des
  Button-Werts. Der neue Wert wird dauerhaft gespeichert (NVS) und mit der
  Web-Oberfläche synchronisiert.
- Werkseinstellung der 9 Presets: **20, 40, 60, 10, 30, 50, 70, 80, 90 dB**.

### Tab „Menu" — Untermenüs

Vier Untermenüpunkte, jeweils mit **Zurück-Button**:

1. **WLAN**
   - Ein/Aus-Schalter für WLAN (0 = aus, AP + Client = ein).
   - Status-Anzeige: AP-SSID, AP-IP, Client-SSID/-IP (falls verbunden).
2. **Info** (schreibgeschützt)
   - Name des Dämpfungsglieds, Relaisanzahl, maximale Dämpfung, Schrittweite,
     Relais-Modus (Bridge/Static), ESP- und Pico-Firmware-Version.
3. **Test**
   - **Start** aktiviert den Testmodus (sendet `TEST:START` an den Pico).
   - Navigation **< Relais >** wählt das zu prüfende Relais aus
     (Bridge 1–9 bzw. Static 10/20/40A/40B).
   - Status-Anzeige **EIN/AUS**, **Puls/Toggle** (sendet `TEST:ACTION`),
     **Beenden** (sendet `TEST:END`).
4. **Verhalten** — Set-Modus auswählen (1 aus 3):
   - **Direct** — UP/DOWN setzt den Wert sofort.
   - **Time** — UP/DOWN setzt den Wert zeitgesteuert.
   - **Set-Button** — der Set-Button erscheint; die Übernahme muss manuell
     bestätigt werden.
   - Die Auswahl wird gespeichert und an den Pico übertragen.

### Wertebereich und Ziffernbegrenzung

- Das Gesamtmaximum der dB Werte ist **nicht fest**, sondern hängt vom erkannten
  Dämpfungsglied ab. Beim Start meldet der Pico Maximalwert und Schrittweite
  (`MAXDB` / `STEP`); typische Werte sind **110 dB** (26.5 GHz, 10 dB-Schritte),
  **135 dB** (RS-135, 5 dB-Schritte) und **141 dB** (RS-141).
- `DIGIT_MAX_VAL` (110) ist lediglich der Vorgabewert im ESP32-Code, bis der Pico
  den tatsächlichen Wert übermittelt; danach gilt der gemeldete Maximalwert.
- Standard-Ziffernbegrenzung vor der Erkennung: Hunderter 0–1, Zehner 0–9, Einer
  gesperrt (10er-Schritte).
- Nach der Erkennung wird die Ziffernbegrenzung aus Maximalwert und Schrittweite
  neu berechnet (die Einer-Stelle wird nur freigeschaltet, wenn die Schrittweite
  kleiner als 10 dB ist).
- Bei direkter Eingabe wird der Wert auf das Maximum begrenzt und auf gesperrte
  Stellen abgerundet (z. B. 33 → 30, wenn die Einer-Stelle gesperrt ist).

---

## B) Web-Oberfläche

Erreichbar im Browser, sobald WLAN aktiv ist:

- Über den Access-Point **`ESP32-ATT`** (Passwort `12345678`), Standard-IP
  `192.168.4.1`.
- Oder nach WLAN-Anbindung im Heimnetz unter **`esp32-att.local`** (mDNS).

Die Seite spiegelt die Display-Funktionen und ist in Echtzeit per WebSocket
synchronisiert (Heartbeat im Sekundentakt hält die Verbindung).

### Hauptbereich — Dämpfungswert

- **3 Ziffern** (anklickbar zur Auswahl der aktiven Stelle).
- **DOWN / UP** — Wert um einen Schritt verringern/erhöhen.
- **Set** — überträgt den Wert (nur im Modus *Set-Button* sichtbar).
- **RF** — HF-Schalter umschalten (nur sichtbar, wenn vorhanden).

### Verhalten — Set-Modus

Drei Schaltflächen wählen den Set-Modus: **Set-Direct**, **Set-Time**,
**Set-Button** (Wirkung identisch zum Display).

### Defaults — Presets

- **3×3-Raster** mit 9 Buttons (Wert + „dB").
- **Kurzer Klick** — Preset anwenden.
- **Langer Klick (ca. 600 ms)** — Zahleneingabe-Dialog zum Bearbeiten; der Wert
  wird dauerhaft gespeichert.

### WLAN-Möglichkeiten

Das Gerät kennt zwei WLAN-Betriebsarten (umschaltbar am Display unter
**Menu → WLAN**, im NVS gespeichert):

- **Aus** — WLAN vollständig deaktiviert; die Web-Oberfläche ist dann nicht
  erreichbar.
- **AP + Client** — der Access Point ist **immer** aktiv, zusätzlich verbindet
  sich das Gerät als Client mit einem vorhandenen WLAN, sobald Zugangsdaten
  hinterlegt sind.

Daraus ergeben sich für den Zugriff über den Browser zwei Wege:

- **Access-Point (immer verfügbar):** direkt mit dem WLAN **`ESP32-ATT`**
  (Passwort `12345678`) verbinden und `http://192.168.4.1` öffnen. Dieser Weg
  funktioniert auch ohne jede Heimnetz-Anbindung.
- **Heimnetz (Client):** nach erfolgreicher Anbindung ist das Gerät zusätzlich
  im normalen WLAN erreichbar — über `http://esp32-att.local` (mDNS) oder die
  angezeigte Client-IP.

#### WLAN einrichten (Bereich „WLAN-Einrichtung", aufklappbar)

- **Netzwerke suchen** — startet einen WLAN-Scan (`/api/scan`), die Ergebnisse
  werden nachgeladen (`/api/scanresult`).
- **Netzwerk-Auswahl** — Dropdown mit den gefundenen Netzwerken.
- **SSID** und **Passwort** — manuelle Eingabe möglich, Passwort mit
  Sichtbarkeits-Umschalter.
- **Verbinden** — speichert die Zugangsdaten dauerhaft (NVS) und verbindet nicht
  blockierend (`/api/connect`). Bei Timeout (ca. 20 s) oder Fehler bleibt der
  Access Point aktiv (Fallback auf AP-only), sodass die Oberfläche erreichbar
  bleibt.
- **Status-Anzeige** — grün bei erfolgreicher Verbindung, rot bei Fehler.

> **Hinweis:** Das komplette Ausschalten des WLANs ist nur am Display möglich,
> nicht über die Web-Oberfläche (das würde die eigene Verbindung trennen).

### Statusbereich

- **LED-Indikator** — grün = verbunden, rot = getrennt (Reconnect läuft).
- **WLAN-Info** — „aus" / „AP + Client" / „AP + Client verbunden" inkl.
  IP-Adressen und Signalstärke.

### HTTP-Endpunkte (technisch)

| Endpunkt | Methode | Funktion |
|---|---|---|
| `/` | GET | Web-Seite |
| `/ws` | WebSocket | Echtzeit-Synchronisation |
| `/api/mode` | GET | aktueller WLAN-Modus |
| `/api/scan` | GET | WLAN-Scan starten |
| `/api/scanresult` | GET | Scan-Ergebnisse abrufen |
| `/api/wifistatus` | GET | Verbindungsstatus (SSID, IP, RSSI, AP-IP) |
| `/api/connect` | POST | WLAN-Zugangsdaten setzen und verbinden |

> **Hinweis:** Ein OTA-Firmware-Update über die Web-Oberfläche ist derzeit
> **nicht** implementiert.

---

## Gemeinsamkeiten

- Beide Oberflächen teilen denselben Zustand (Dämpfungswert, Presets, Set-Modus,
  RF-Schalter, WLAN-Einstellungen) und sind per WebSocket synchronisiert.
- Preset-Werte, Set-Modus, WLAN-Modus und Zugangsdaten werden im NVS des ESP32
  gespeichert und überstehen einen Neustart.

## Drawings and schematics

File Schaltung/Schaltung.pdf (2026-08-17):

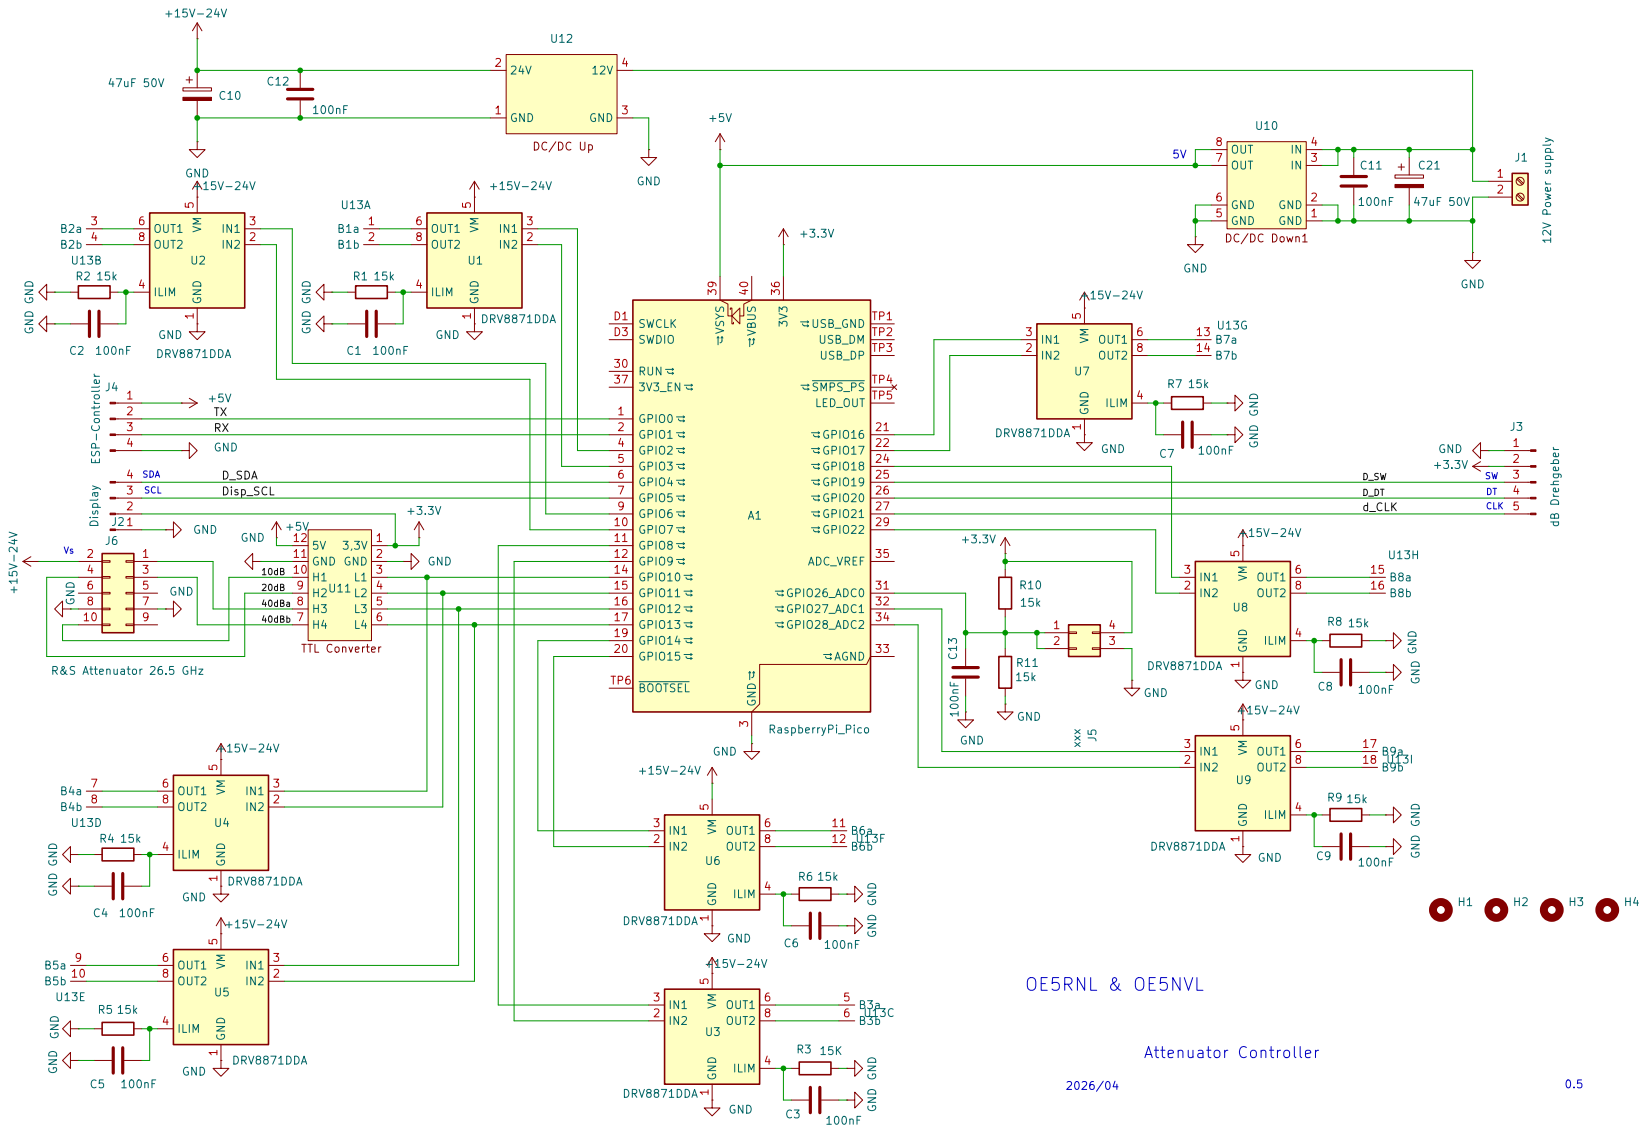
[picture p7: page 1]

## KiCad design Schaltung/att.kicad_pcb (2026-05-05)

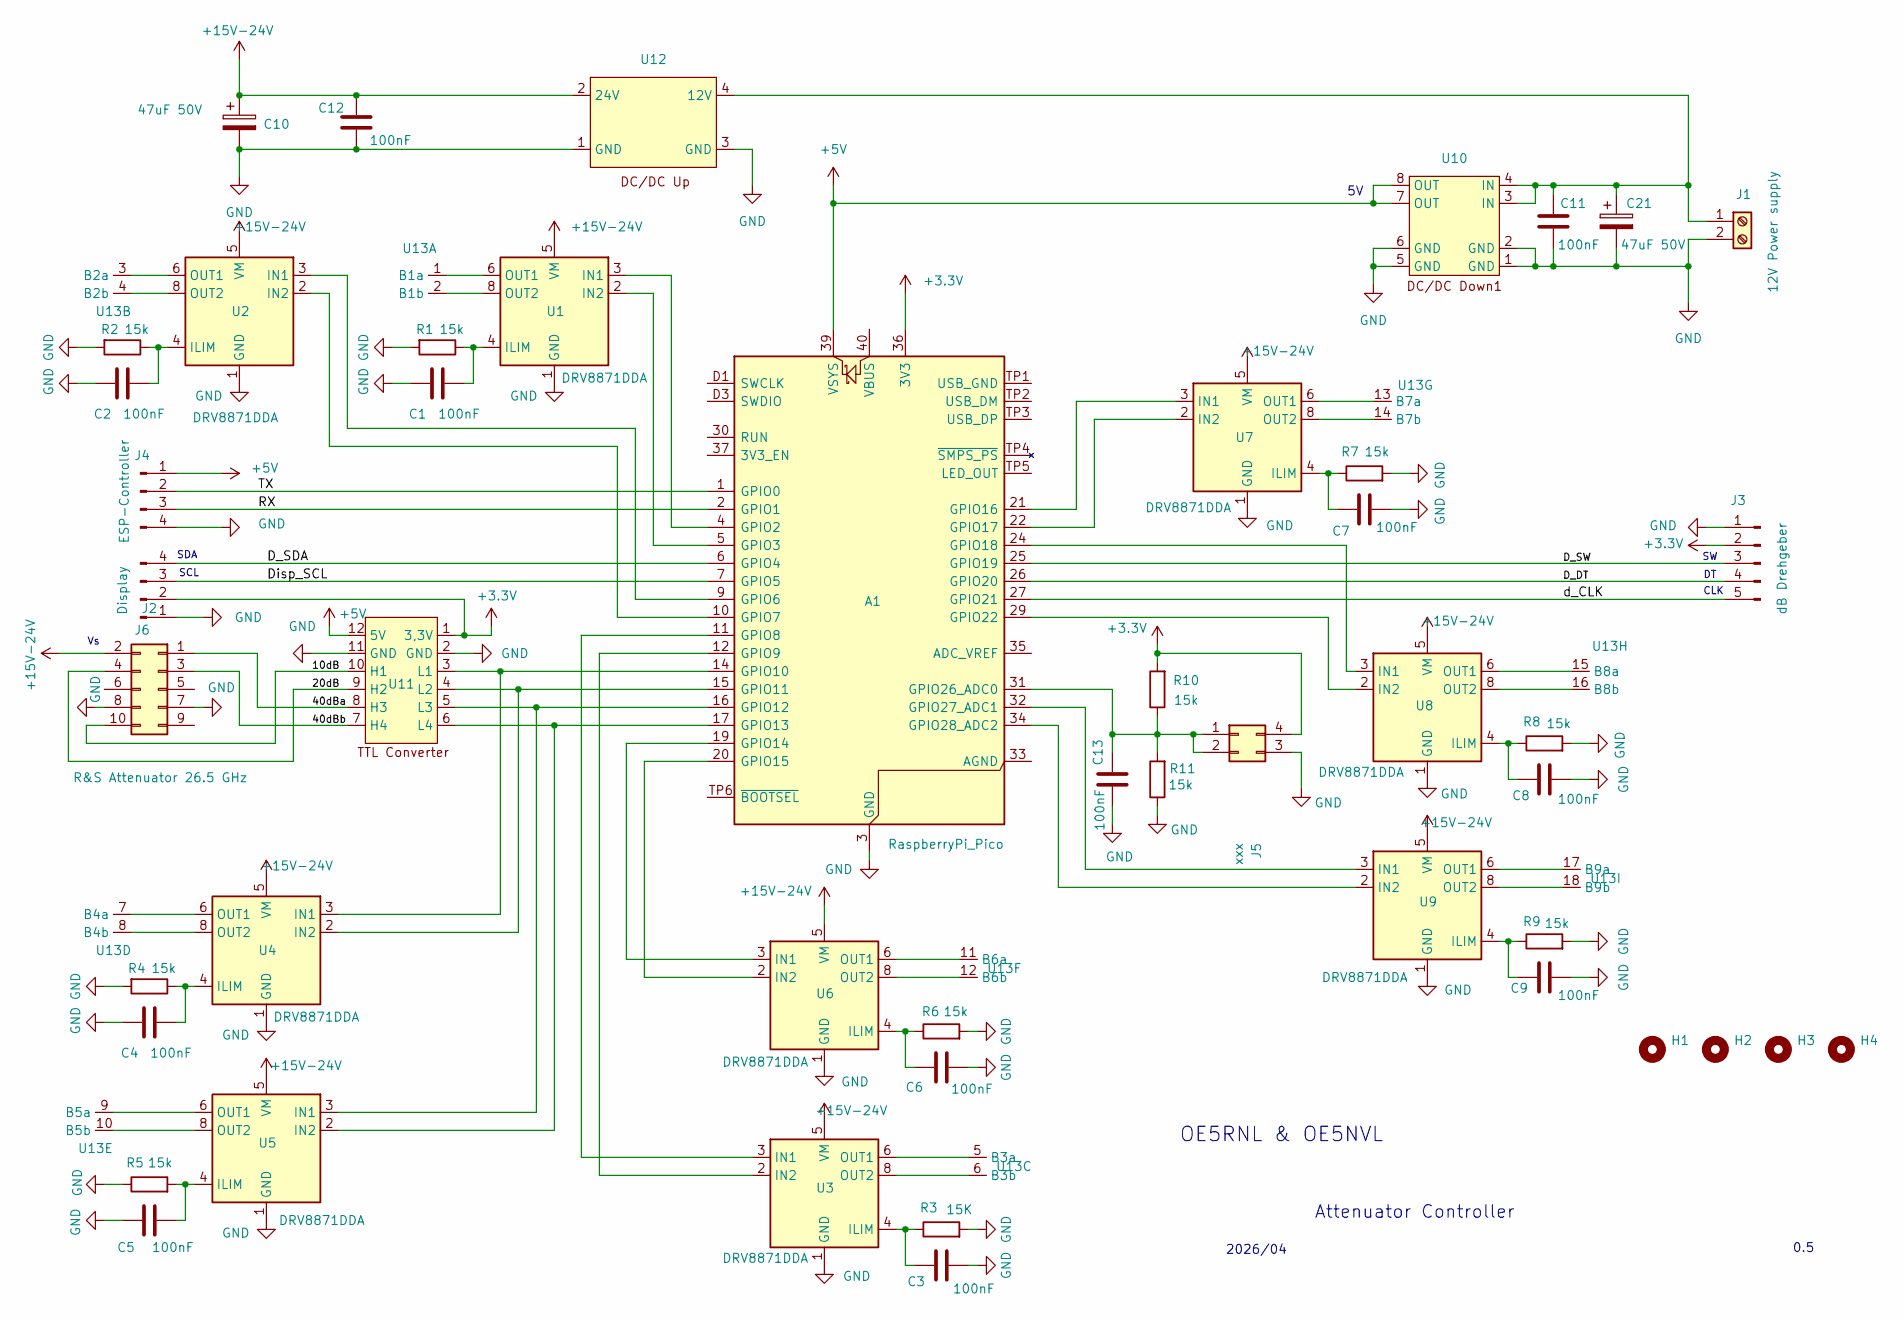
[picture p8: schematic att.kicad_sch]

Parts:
A1: RaspberryPi_Pico; RaspberryPi_Pico_SMD
C1, C2, C3, C4, C5, C6, C7, C8, C9, C11, C12, C13: 100nF; C_0805_2012Metric
C10: 47uF 50V; CP_Radial_D8.0mm_P5.00mm
C21: 47uF 50V; CP_Elec_6.3x5.2
H1, H2, H3, H4: MountingHole; MountingHole_2.5mm
J1: 12V Power supply; TerminalBlock_MetzConnect_Type055_RT01502HDWU_1x02_P5.00mm_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
J2: R&S Attenuator 26.5 GHz; PinHeader_2x05_P2.54mm_Vertical
J3: dB Drehgeber; PinHeader_1x05_P2.54mm_Vertical
J4: ESP-Controller; PinHeader_1x04_P2.54mm_Vertical
J5: xxx; PinHeader_2x02_P2.54mm_Vertical
J6: Display; PinHeader_1x04_P2.54mm_Vertical
R1, R2, R4, R5, R6, R7, R8, R9, R10, R11: 15k; R_0805_2012Metric
R3: 15K; R_0805_2012Metric
U1, U2, U3, U4, U5, U6, U7, U8, U9: DRV8871DDA; Texas_HTSOP-8-1EP_3.9x4.9mm_P1.27mm_EP2.95x4.9mm_Mask2.4x3.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
U10: DC-DC_12_5
U11: ttl_converter
U12: DC-DC_12_24
U13: SIL_18

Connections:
+3.3V: A1.36 (3V3), J3.2, J5.4, J6.2, R10.2, U11.1 (3,3V)
+5V: A1.39 (VSYS), J4.1, U10.7 (OUT), U10.8 (OUT), U11.12 (5V)
+15V-24V: C10.1, C12.2, J2.2 (Pin_10), U1.5 (VM), U2.5 (VM), U3.5 (VM), U4.5 (VM), U5.5 (VM), U6.5 (VM), U7.5 (VM), U8.5 (VM), U9.5 (VM), U12.2 (24V)
/10dB: J2.10 (Pin_6), U11.10 (H1)
/20dB: J2.4 (Pin_9), U11.9 (H2)
/40dBa: J2.1, U11.8 (H3)
/40dBb: J2.3 (Pin_2), U11.7 (H4)
/D_DT: A1.26 (GPIO20), J3.4
/D_SDA: A1.6 (GPIO4), J6.4
/D_SW: A1.25 (GPIO19), J3.3
/Disp_SCL: A1.7 (GPIO5), J6.3
/RX: A1.2 (GPIO1), J4.3
/TX: A1.1 (GPIO0), J4.2
/d_CLK: A1.27 (GPIO21), J3.5
GND: A1.3 (GND), A1.8 (GND), A1.13 (GND), A1.18 (GND), A1.23 (GND), A1.28 (GND), A1.38 (GND), A1.D2 (GND), C1.1, C2.1, C3.2, C4.1, C5.1, C6.2, C7.2, C8.2, C9.2, C10.2, C11.1, C12.1, C13.1, C21.2, J1.2, J2.7 (Pin_4), J2.8 (Pin_7), J3.1, J4.4, J5.3, J6.1, R1.2, R2.2, R3.2, R4.2, R5.1, R6.2, R7.2, R8.2, R9.2, R11.1, U1.1 (GND), U1.7 (GND), U1.9 (GND), U2.1 (GND), U2.7 (GND), U2.9 (GND), U3.1 (GND), U3.7 (GND), U3.9 (GND), U4.1 (GND), U4.7 (GND), U4.9 (GND), U5.1 (GND), U5.7 (GND), U5.9 (GND), U6.1 (GND), U6.7 (GND), U6.9 (GND), U7.1 (GND), U7.7 (GND), U7.9 (GND), U8.1 (GND), U8.7 (GND), U8.9 (GND), U9.1 (GND), U9.7 (GND), U9.9 (GND), U10.1 (GND), U10.2 (GND), U10.5 (GND), U10.6 (GND), U11.2 (GND), U11.11 (GND), U12.1 (GND), U12.3 (GND)
unnamed: A1.4 (GPIO2), U1.3 (IN1)
unnamed: A1.5 (GPIO3), U1.2 (IN2)
unnamed: A1.9 (GPIO6), U2.3 (IN1)
unnamed: A1.10 (GPIO7), U2.2 (IN2)
unnamed: A1.11 (GPIO8), U3.3 (IN1)
unnamed: A1.12 (GPIO9), U3.2 (IN2)
unnamed: A1.14 (GPIO10), U4.3 (IN1), U11.3 (L1)
unnamed: A1.15 (GPIO11), U4.2 (IN2), U11.4 (L2)
unnamed: A1.16 (GPIO12), U5.3 (IN1), U11.5 (L3)
unnamed: A1.17 (GPIO13), U5.2 (IN2), U11.6 (L4)
unnamed: A1.19 (GPIO14), U6.3 (IN1)
unnamed: A1.20 (GPIO15), U6.2 (IN2)
unnamed: A1.21 (GPIO16), U7.3 (IN1)
unnamed: A1.22 (GPIO17), U7.2 (IN2)
unnamed: A1.24 (GPIO18), U8.3 (IN1)
unnamed: A1.29 (GPIO22), U8.2 (IN2)
unnamed: A1.31 (GPIO26_ADC0), C13.2, J5.1, J5.2, R10.1, R11.2
unnamed: A1.32 (GPIO27_ADC1), U9.3 (IN1)
unnamed: A1.34 (GPIO28_ADC2), U9.2 (IN2)
unnamed: C11.2, C21.1, J1.1, U10.3 (IN), U10.4 (IN), U12.4 (12V)
unnamed: C1.2, R1.1, U1.4 (ILIM)
unnamed: U1.6 (OUT1), U13.1 (B1a)
unnamed: U1.8 (OUT2), U13.2 (B1b)
unnamed: C2.2, R2.1, U2.4 (ILIM)
unnamed: C3.1, R3.1, U3.4 (ILIM)
unnamed: C4.2, R4.1, U4.4 (ILIM)
unnamed: C5.2, R5.2, U5.4 (ILIM)
unnamed: C6.1, R6.1, U6.4 (ILIM)
unnamed: C7.1, R7.1, U7.4 (ILIM)
unnamed: C8.1, R8.1, U8.4 (ILIM)
unnamed: C9.1, R9.1, U9.4 (ILIM)
unnamed: U2.6 (OUT1), U13.3 (B2a)
unnamed: U2.8 (OUT2), U13.4 (B2b)
unnamed: U3.6 (OUT1), U13.5 (B3a)
unnamed: U3.8 (OUT2), U13.6 (B3b)
unnamed: U4.6 (OUT1), U13.7 (B4a)
unnamed: U4.8 (OUT2), U13.8 (B4b)
unnamed: U5.6 (OUT1), U13.9 (B5a)
unnamed: U5.8 (OUT2), U13.10 (B5b)
unnamed: U6.6 (OUT1), U13.11 (B6a)
unnamed: U6.8 (OUT2), U13.12 (B6b)
unnamed: U7.6 (OUT1), U13.13 (B7a)
unnamed: U7.8 (OUT2), U13.14 (B7b)
unnamed: U8.6 (OUT1), U13.15 (B8a)
unnamed: U8.8 (OUT2), U13.16 (B8b)
unnamed: U9.6 (OUT1), U13.17 (B9a)
unnamed: U9.8 (OUT2), U13.18 (B9b)

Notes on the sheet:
Attenuator Controller
0.5
OE5RNL & OE5NVL
CLK
SCL
SDA
2026/04

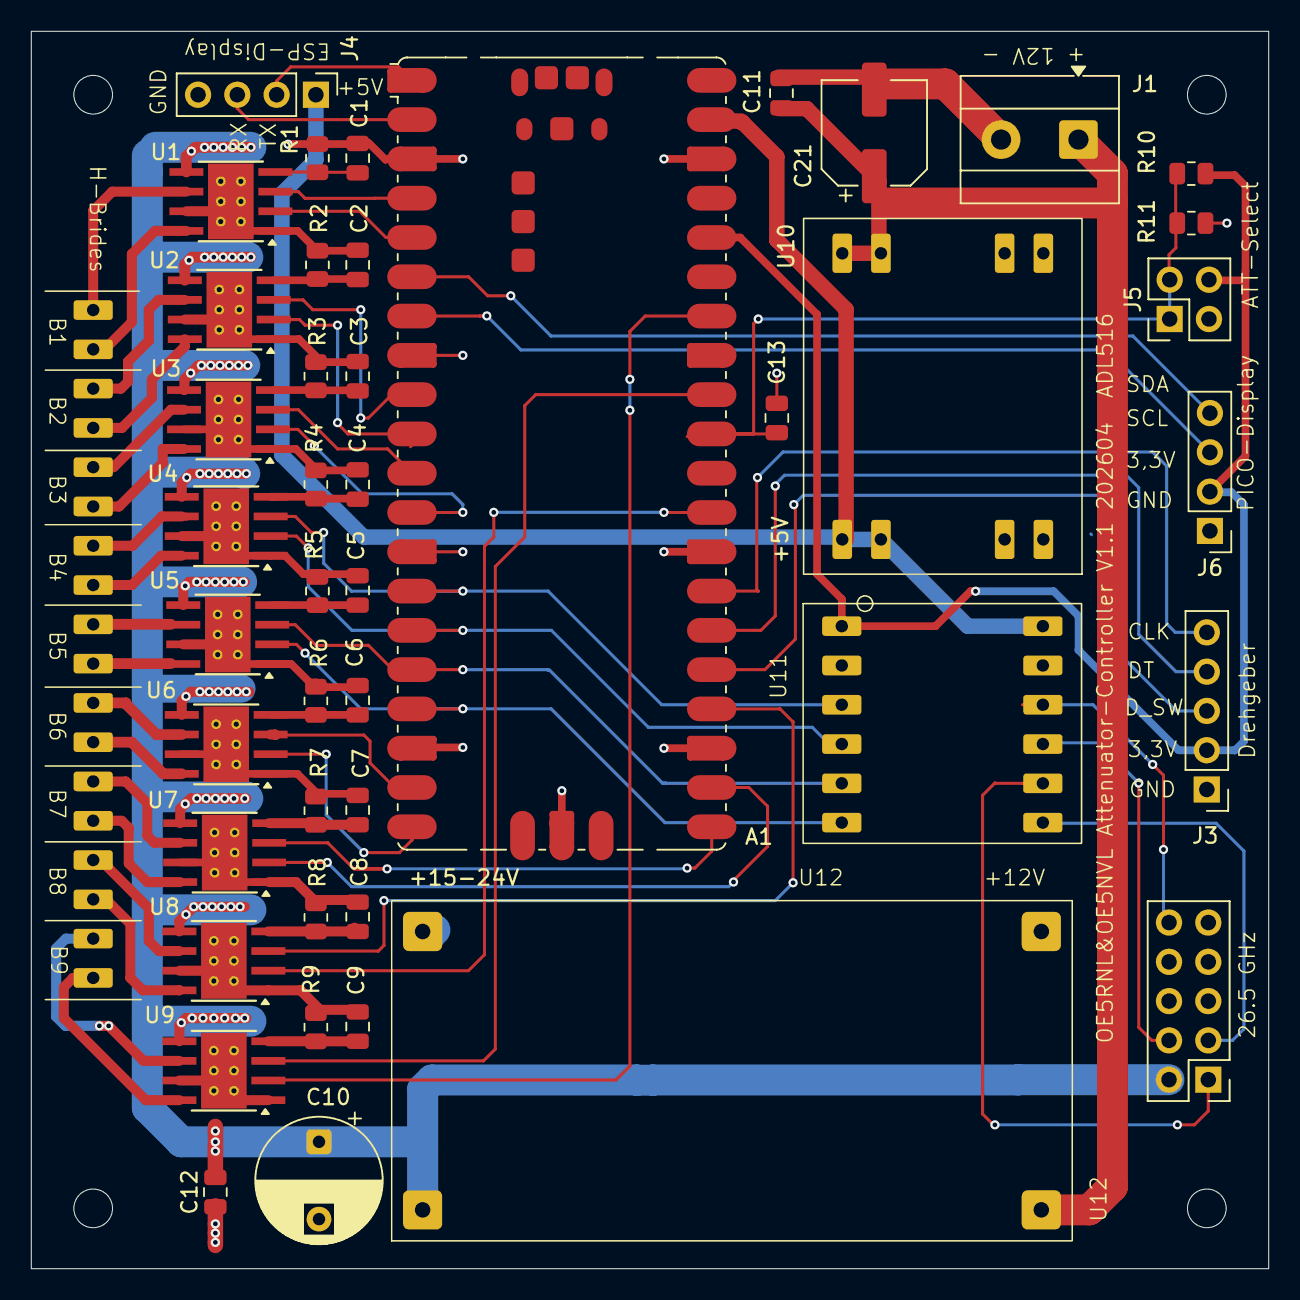
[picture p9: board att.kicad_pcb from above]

Board: 2 copper layers, 80.0 x 80.0 mm, 49 parts (0 on the bottom side), 62 nets.

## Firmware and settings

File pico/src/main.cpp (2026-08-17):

/* Raspberry Pi Pico - Attenuator Controller
 *
 * Version:  shared/version.h 
 *
 * Hardware: Raspberry Pi Pico
 *
 * serial.println  gibt über die USB zum PC (debug) ausgegeben
 * Serial1.println spricht über GPIO1 (TX) (RX) mit dem ESP32
 *  für die Ermitteltes tAttenuator, Synchronisation von db-Wert, AUTO-Set und Digit-Auswahl...
 *
 * Modular structure:
 *   Attenuator.h/cpp   – abstract base class + factory (create_attenuator)
 *   att_26ghz.*        – R&S 26.5 GHz (H-bridge, 10 dB steps)
 *   att_135db.*        – R&S 135 dB   (bistable relays, 5 dB steps)
 *   att_a.*            – Stub for unknown type A
 *   att_b.*            – Stub for unknown type B
 *   att_types.h        – type constants, ADC_SELECT_PIN, getAttenuator()
 */

#include <Arduino.h>
#include <Wire.h>
#include <cstdio>
#include <BlockDevice.h>
#include <LittleFileSystem.h>
#include "SSD1306.h"
#include "att_types.h"
#include "Attenuator.h"
#include "test.h"

#include "version.h"


/* I2C Display SSD1306 (128x64) using I2C0 on GPIO4 PIN6 (SDA) / GPIO5 PIN7 (SCL) */
SSD1306 display(&Wire);

/* KY-040 Rotary Encoder */
#define ENCODER_SW     19   // Pin 25 Switch/Button
#define ENCODER_DT     20   // Pin 26 Data (Direction)
#define ENCODER_CLK    21   // Pin 27 Clock (Pulse)


/* -------------------------------------------------------
 * Active attenuator instance (set once in setup())
 * ------------------------------------------------------- */
static Attenuator* att = nullptr;


/* -------------------------------------------------------
 * Global State
 * ------------------------------------------------------- */

static int32_t current_db = 0;
static unsigned long last_led_toggle = 0;
static bool led_state = false;
static bool led_solid_mode = false;
static unsigned long led_solid_start = 0;
static String serial_buffer = "";

/* Rotary Encoder State */
static int encoder_last_clk = HIGH;
static int encoder_last_sw  = HIGH;
static int encoder_position = 0;
static unsigned long last_encoder_change = 0;
static bool encoder_apply_pending = false;
static unsigned long button_press_start = 0;
static bool button_was_pressed = false;
static bool long_press_executed = false;
static bool suppress_relay_update = false;

static const unsigned long ENCODER_SETTLE_TIME = 300;
static const unsigned long LONG_PRESS_TIME      = 800;
static const unsigned long TIMED_SETTLE_TIME    = 300;
static bool          timed_apply_pending = false;
static unsigned long timed_last_rx       = 0;

/* Doppelklick-Erkennung */
static unsigned long last_click_time = 0;
static bool waiting_for_double_click = false;
static const unsigned long DOUBLE_CLICK_TIME = 1000;

/* Display Cursor State */
static int selected_digit = 1;  /* 0 = Hunderter, 1 = Zehner */

/* AUTO-Set Mode */
static bool auto_set_mode = true;
static int  pico_set_mode = 0;   /* 0=Direct, 1=Time, 2=Button */
static bool pico_set_pending = false;  /* set_mode==2: dB geaendert, noch nicht via Set angewendet */

static const char* pico_set_mode_str() {
    if(pico_set_mode == 1) return "SET-TIME";
    if(pico_set_mode == 2) return "SET-BUTTON";
    return "SET-DIRECT";
}

/* -------------------------------------------------------
 * Remote-Test-Modus (gesteuert vom ESP32 per Serial1)
 * ------------------------------------------------------- */
static bool  rmt_test_active    = false;
static bool  rmt_test_is_bridge = false;
static int   rmt_test_sel       = 0;
static int   rmt_test_count     = 0;
/* Bridge-Test-Pins (identisch mit test.cpp) */
static const int RMT_HB_COUNT       = 9;
static const int rmt_hb_pin_a[9]    = {  2,  6,  8, 10, 12, 14, 16, 18, 27 };
static const int rmt_hb_pin_b[9]    = {  3,  7,  9, 11, 13, 15, 17, 22, 28 };
static int   rmt_hb_states[9]       = {};
/* Static-Test-Pins */
static const int RMT_SG_COUNT       = 4;
static const int rmt_sg_pins[4]     = { 10, 11, 12, 13 };
static bool  rmt_sg_states[4]       = {};

static const int32_t STARTUP_DB = 0;
static int32_t persisted_db_cache = -1000;
static mbed::BlockDevice * storage_bd = nullptr;
static mbed::LittleFileSystem storage_fs("fs");
static bool storage_ready = false;
static bool has_persisted_db = false;
static const char * DB_STORE_FILE      = "/fs/att_db.txt";
static const char * SETMODE_STORE_FILE = "/fs/setmode.txt";
static const char * RF_STORE_FILE      = "/fs/rfstate.txt";
static int          rf_persisted_cache = -1;   /* -1 = unbekannt, 0/1 = letzter persistierter Wert */

/* -------------------------------------------------------
 * Persistent Storage
 * ------------------------------------------------------- */

static void init_persistent_storage()
{
    storage_bd = mbed::BlockDevice::get_default_instance();
    if(!storage_bd) return;

    int err = storage_fs.mount(storage_bd);
    if(err) {
        err = storage_fs.reformat(storage_bd);
        if(err) return;
        err = storage_fs.mount(storage_bd);
        if(err) return;
    }
    storage_ready = true;
}

static void load_persisted_db()
{
    current_db = STARTUP_DB;
    has_persisted_db = false;
    if(storage_ready) {
        FILE * f = fopen(DB_STORE_FILE, "r");
        if(f) {
            int stored = STARTUP_DB;
            if(fscanf(f, "%d", &stored) == 1 && stored >= 0 && stored <= 999) {
                current_db = stored;
                has_persisted_db = true;
            }
            fclose(f);
        }
    }
    persisted_db_cache = current_db;
}

static void save_persisted_db_if_changed(int32_t db_value)
{
    if(db_value < 0) db_value = 0;
    if(db_value == persisted_db_cache) return;
    if(!storage_ready) return;

    FILE * f = fopen(DB_STORE_FILE, "w");
    if(!f) return;
    fprintf(f, "%d\n", (int)db_value);
    fclose(f);
    has_persisted_db = true;
    persisted_db_cache = db_value;
}

static void load_persisted_setmode()
{
    if(!storage_ready) return;
    FILE * f = fopen(SETMODE_STORE_FILE, "r");
    if(!f) return;
    int m = 0;
    if(fscanf(f, "%d", &m) == 1 && m >= 0 && m <= 2) {
        pico_set_mode = m;
        auto_set_mode = (pico_set_mode != 2);
    }
    fclose(f);
}

static void save_persisted_setmode()
{
    if(!storage_ready) return;
    FILE * f = fopen(SETMODE_STORE_FILE, "w");
    if(!f) return;
    fprintf(f, "%d\n", pico_set_mode);
    fclose(f);
}

/* RF-Schalter-Zustand persistieren (Default: AN). */
static bool load_persisted_rf_state(bool default_on)
{
    bool state = default_on;
    if(storage_ready) {
        FILE * f = fopen(RF_STORE_FILE, "r");
        if(f) {
            int v = default_on ? 1 : 0;
            if(fscanf(f, "%d", &v) == 1) state = (v != 0);
            fclose(f);
        }
    }
    rf_persisted_cache = state ? 1 : 0;
    return state;
}

static void save_persisted_rf_state(bool state)
{
    int v = state ? 1 : 0;
    if(rf_persisted_cache == v) return;
    if(!storage_ready) return;
    FILE * f = fopen(RF_STORE_FILE, "w");
    if(!f) return;
    fprintf(f, "%d\n", v);
    fclose(f);
    rf_persisted_cache = v;
}

static void sync_state_to_esp32()
{
    if(has_persisted_db) {
        Serial1.print(current_db);
        Serial1.println("dB");
    }
    Serial1.print("SETMODE:");
    Serial1.println(pico_set_mode);
    Serial1.print("SEL");
    Serial1.println(selected_digit);
    if(att && att->rf_switch()) {
        Serial1.print("RF:");
        Serial1.println(att->get_rf() ? 1 : 0);
    }
}

static void send_info_to_esp32()
{
    Serial1.print("RELAYS:");
    Serial1.println(att ? att->relay_count() : 0);
    Serial1.print("ATTNAME:");
    Serial1.println(att ? att->att_name() : "UNKNOWN");
    /* DIGITS: entfällt – ESP32 leitet das aus STEP + MAXDB ab */
    Serial1.print("STEP:");
    Serial1.println(att ? (int)att->step_db() : 10);
    Serial1.print("MAXDB:");
    Serial1.println(att ? (int)att->max_db() : 110);
    Serial1.print("RELMODE:");
    Serial1.println(att ? att->relay_mode() : BRIDGE);
    Serial1.print("RFSWITCH:");
    Serial1.println(att && att->rf_switch() ? 1 : 0);
    Serial1.print("PICOVER:");
    Serial1.println(PICO_VERSION);
}

/* -------------------------------------------------------
 * Remote-Test-Funktionen (ESP32-gesteuert, non-blocking)
 * ------------------------------------------------------- */
static void rmt_test_send_state()
{
    int s = rmt_test_is_bridge ? rmt_hb_states[rmt_test_sel]
                               : (int)rmt_sg_states[rmt_test_sel];
    Serial1.print("TESTSTATE:");
    Serial1.print(rmt_test_sel);
    Serial1.print(",");
    Serial1.println(s);
}

static void rmt_test_start()
{
    rmt_test_is_bridge = !att || (att->relay_mode() == BRIDGE);
    rmt_test_sel       = 0;
    if(rmt_test_is_bridge) {
        rmt_test_count = RMT_HB_COUNT;
        for(int i = 0; i < RMT_HB_COUNT; i++) rmt_hb_states[i] = 0;
        for(int i = 0; i < RMT_HB_COUNT; i++) {
            pinMode(rmt_hb_pin_a[i], OUTPUT); digitalWrite(rmt_hb_pin_a[i], LOW);
            pinMode(rmt_hb_pin_b[i], OUTPUT); digitalWrite(rmt_hb_pin_b[i], LOW);
        }
    } else {
        rmt_test_count = RMT_SG_COUNT;
        for(int i = 0; i < RMT_SG_COUNT; i++) rmt_sg_states[i] = false;
        for(int i = 0; i < RMT_SG_COUNT; i++) {
            pinMode(rmt_sg_pins[i], OUTPUT);
            digitalWrite(rmt_sg_pins[i], LOW);
        }
    }
    rmt_test_active = true;
    rmt_test_send_state();
}

static void rmt_test_select(int idx)
{
    if(idx < 0 || idx >= rmt_test_count) return;
    rmt_test_sel = idx;
    rmt_test_send_state();
}

static void rmt_test_action()
{
    int i = rmt_test_sel;
    if(rmt_test_is_bridge) {
        if(rmt_hb_states[i] == 0) {
            digitalWrite(rmt_hb_pin_a[i], HIGH); delay(20); digitalWrite(rmt_hb_pin_a[i], LOW);
        } else {
            digitalWrite(rmt_hb_pin_b[i], HIGH); delay(20); digitalWrite(rmt_hb_pin_b[i], LOW);
        }
        rmt_hb_states[i] = 1 - rmt_hb_states[i];
    } else {
        rmt_sg_states[i] = !rmt_sg_states[i];
        digitalWrite(rmt_sg_pins[i], rmt_sg_states[i] ? HIGH : LOW);
    }
    rmt_test_send_state();
}

static void rmt_test_end()
{
    if(rmt_test_is_bridge) {
        for(int i = 0; i < RMT_HB_COUNT; i++) {
            digitalWrite(rmt_hb_pin_a[i], LOW);
            digitalWrite(rmt_hb_pin_b[i], LOW);
        }
    } else {
        for(int i = 0; i < RMT_SG_COUNT; i++) {
            digitalWrite(rmt_sg_pins[i], LOW);
        }
    }
    rmt_test_active = false;
}

/* -------------------------------------------------------
 * Attenuator Type Detection
 * ------------------------------------------------------- */

int getAttenuator()
{
    // analogReadResolution(12);
    int raw = analogRead(ADC_SELECT_PIN);
    float v = (float)raw / 4095.0f * 3.3f;

    Serial.print("Analog: raw=");
    Serial.print(raw);
    Serial.print(" float=");
    Serial.println(v, 3);

    if(v >= 0.0f && v < 0.7f) return ATTENUATOR_RS_141DB;
    if(v >= 0.9f && v < 1.5f) return ATTENUATOR_26_5GHz;
    if(v >= 1.7f && v < 2.3f) return ATTENUATOR_B;
    if(v >= 2.4f && v <= 3.3f) return ATTENUATOR_RS_135DB;
    return -1;   // ausserhalb aller Fenster -> NOT IMPLEMENTED, kein GPIO
}

/* -------------------------------------------------------
 * Display helpers
 * ------------------------------------------------------- */

static void drawCursor()
{
    uint8_t cursor_y = 49;
    uint8_t cursor_x = 10 + (uint8_t)selected_digit * 26;
    for(uint8_t i = 0; i < 24; i++) {
        display.setPixel(cursor_x + i, cursor_y, true);
    }
}

static void update_attenuation_display_state(int32_t db_value)
{
    int32_t dv = db_value;
    if(dv < 0) dv = 0;

    int32_t prev_db = current_db;
    current_db = dv;
    if(current_db != prev_db) {
        save_persisted_db_if_changed(current_db);
    }

    display.clear();
    display.drawBigNumber(10, 16, (uint16_t)dv);
    display.drawString(90, 28, "dB");
    drawCursor();
    display.drawString(0, 56, pico_set_mode_str());
    int rf_w = 0;
    if(pico_set_mode == 2 && pico_set_pending) {
        int star_x = (rf_w > 0) ? (128 - rf_w - 12) : (128 - 8);
        display.drawString(star_x, 56, "*");
    }
    display.display();
}

static void refresh_attenuation_display()
{
    update_attenuation_display_state(current_db);
}

/* -------------------------------------------------------
 * Attenuation application
 * ------------------------------------------------------- */

static void apply_relays(int32_t db_value)
{
    if(att) att->apply(db_value);
}

static void apply_attenuation(int32_t db_value)
{
    update_attenuation_display_state(db_value);
    if(!suppress_relay_update) apply_relays(db_value);
}

static void apply_attenuation_from_esp_db(int32_t db_value)
{
    if(pico_set_mode == 2 && db_value != current_db) pico_set_pending = true;
    update_attenuation_display_state(db_value);
    if(!auto_set_mode) {
        Serial.print("ESP32 dB command -> display only: ");
        Serial.print(current_db);
        Serial.println(" dB");
        return;
    }
    /* Coalesce schnelle Repeats: Relais erst schalten wenn keine weiteren
     * Frames im UART-RX-Puffer warten (spart delay(20) je Bit-Wechsel). */
    if(Serial1.available()) return;
    if(!suppress_relay_update) apply_relays(current_db);
}

static void apply_attenuation_from_esp_set(int32_t db_value)
{
    pico_set_pending = false;
    update_attenuation_display_state(db_value);
    if(!suppress_relay_update) apply_relays(current_db);
}

/* -------------------------------------------------------
 * Encoder helpers (depend on active attenuator)
 * ------------------------------------------------------- */

static int encoder_step()
{
    if(selected_digit == 0) return 100;
    if(selected_digit == 1) return 10;
    return att ? att->step_db() : 1;
}

static int32_t att_max_db()
{
    return att ? att->max_db() : 110;
}

/* -------------------------------------------------------
 * Info screen: zeigt erkannten Attenuator + ADC-Spannung,
 * wartet auf Tastendruck, dann zurueck ins Menue.
 * ------------------------------------------------------- */
static void info_screen()
{
    /* Taste vom Menü-Klick kann noch gedrückt sein – erst loslassen abwarten */
    while(digitalRead(ENCODER_SW) == LOW) { delay(10); }
    delay(50);

    analogReadResolution(12);
    int adc_raw = analogRead(ADC_SELECT_PIN);
    float adc_v = (float)adc_raw / 4095.0f * 3.3f;
    int att_code = getAttenuator();
    const char* att_label = att ? att->att_name() : "UNKNOWN";
    char buf[24];
    display.clear();
    //display.drawString(15,  0, "Att detected");
    //snprintf(buf, sizeof(buf), "ADC:%d.%02dV %d",(int)adc_v, (int)(adc_v * 100) % 100, adc_raw);

   
    snprintf(buf, sizeof(buf), "Code:%d %s", att_code, att_label);
    display.drawString(0, 0, buf);

    snprintf(buf, sizeof(buf), "ADC    : %d.%02dV",(int)adc_v, (int)(adc_v * 100) % 100);
    display.drawString(0, 14, buf);
 
    snprintf(buf, sizeof(buf), "P-Vers.: %s", PICO_VERSION);
    display.drawString(0, 26, buf);

    snprintf(buf, sizeof(buf), "E-Vers.: %s", ESP_VERSION);
    display.drawString(0, 38, buf);


    display.drawString(0, 56, "Taste: zurueck");
    display.display();

    /* Auf naechsten Tastendruck warten, dann Loslassen abwarten */
    while(digitalRead(ENCODER_SW) == HIGH) { delay(10); }
    while(digitalRead(ENCODER_SW) == LOW)  { delay(10); }
    delay(50);
}
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
void loop()
{
    unsigned long now = millis();

    /* Hardware safety watchdog – must run first, unconditionally */
    if(att) att->poll();

    /* LED control */
    if(led_solid_mode) {
        if(now - led_solid_start >= 2000) {
            led_solid_mode = false;
            last_led_toggle = now;
        }
    } else {
        if(now - last_led_toggle >= 300) {
            last_led_toggle = now;
            led_state = !led_state;
            digitalWrite(LED_BUILTIN, led_state ? HIGH : LOW);
        }
    }

    /* Read KY-040 Rotary Encoder */
    int clk_state = digitalRead(ENCODER_CLK);
    if(clk_state != encoder_last_clk && clk_state == LOW) {
        Serial.println("*\n");
        int step      = encoder_step();
        int32_t max_v = att_max_db();
        int new_db    = current_db;

        if(digitalRead(ENCODER_DT) != clk_state) {
            new_db += step;
            if(new_db > max_v) new_db = max_v;
            encoder_position++;
        } else {
            new_db -= step;
            if(new_db < 0) new_db = 0;
            encoder_position--;
        }

        if(new_db != current_db) {
            if(pico_set_mode == 0) {
                /* Set-Direct: Relais sofort schalten */
                apply_attenuation(new_db);
                encoder_apply_pending = false;
            } else {
                /* Set-Time (1) + Set-Button (2): nur Anzeige */
                if(pico_set_mode == 2) pico_set_pending = true;
                suppress_relay_update = true;
                apply_attenuation(new_db);
                suppress_relay_update = false;
                if(pico_set_mode == 1) {
                    encoder_apply_pending = true;
                    last_encoder_change   = now;
                }
            }

            Serial1.print(current_db);
            Serial1.println("dB");

            led_solid_mode  = true;
            led_solid_start = now;
            digitalWrite(LED_BUILTIN, HIGH);
        }
    }
    encoder_last_clk = clk_state;

    if(encoder_apply_pending && (now - last_encoder_change) >= ENCODER_SETTLE_TIME) {
        encoder_apply_pending = false;
        Serial.print("Encoder settled -> apply ");
        Serial.print(current_db);
        Serial.println(" dB");
        apply_relays(current_db);
        Serial1.print(current_db);
        Serial1.println("dB");
    }

    /* Set-Time: nach Ruhe der TIMED-Frames Relais schalten */
    if(timed_apply_pending && (now - timed_last_rx) >= TIMED_SETTLE_TIME) {
        timed_apply_pending = false;
        Serial.print("TIMED settled -> apply ");
        Serial.print(current_db);
        Serial.println(" dB");
        apply_relays(current_db);
        Serial1.print(current_db);
        Serial1.println("dB");
        led_solid_mode  = true;
        led_solid_start = now;
        digitalWrite(LED_BUILTIN, HIGH);
    }

    /* Read Encoder Button */
    int sw_state = digitalRead(ENCODER_SW);

    if(sw_state == LOW && encoder_last_sw == HIGH) {
        button_press_start   = now;
        button_was_pressed   = true;
        long_press_executed  = false;
    }

    /* LongPress -> Runtime-Menue anzeigen */
    if(button_was_pressed && !long_press_executed && sw_state == LOW
       && (now - button_press_start) >= LONG_PRESS_TIME) {
        long_press_executed = true;
        runtime_menu();
        refresh_attenuation_display();
    }

    if(sw_state == HIGH && encoder_last_sw == LOW && button_was_pressed) {
        button_was_pressed = false;

        if(!long_press_executed) {
            if(pico_set_mode == 2) {
                /* Set-Button: einfacher Klick übernimmt sofort */
                Serial.print("SET-BUTTON CLICK -> Apply value: ");
                Serial.print(current_db);
                Serial.println(" dB");
                waiting_for_double_click = false;
                bool had_pending = pico_set_pending;
                pico_set_pending = false;
                apply_relays(current_db);
                Serial1.print(current_db);
                Serial1.println("dB");
                Serial1.println("SETOK");
                if(had_pending) refresh_attenuation_display();
                led_solid_mode  = true;
                led_solid_start = now;
                digitalWrite(LED_BUILTIN, HIGH);
            } else if(waiting_for_double_click && (now - last_click_time) < DOUBLE_CLICK_TIME) {
                Serial.println("DOUBLE CLICK -> Toggle Digit Selection");
                waiting_for_double_click = false;
                selected_digit = next_active_digit(selected_digit, +1);
                refresh_attenuation_display();
                Serial1.print("SEL");
                Serial1.println(selected_digit);
                led_solid_mode  = true;
                led_solid_start = now;
                digitalWrite(LED_BUILTIN, HIGH);
            } else {
                waiting_for_double_click = true;
                last_click_time = now;
            }
        }
    }
    encoder_last_sw = sw_state;

    if(waiting_for_double_click && (now - last_click_time) >= DOUBLE_CLICK_TIME) {
        waiting_for_double_click = false;
        if(!auto_set_mode) {
            Serial.print("SINGLE CLICK -> Apply value: ");
            Serial.print(current_db);
            Serial.println(" dB (AUTO-Set was OFF)");
            apply_relays(current_db);
            Serial1.print(current_db);
            Serial1.println("dB");
            led_solid_mode  = true;
            led_solid_start = now;
            digitalWrite(LED_BUILTIN, HIGH);
        }
    }

    /* Check Serial1 (from ESP32) */
    if(Serial1.available()) {
        String input = Serial1.readStringUntil('\n');
        input.trim();
        Serial.print("RX from ESP: \""); Serial.print(input); Serial.println("\"");
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

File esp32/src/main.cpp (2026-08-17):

/* ESP32-ATT-C-LVGL8
 *
 * 26.5 GHz Attenuator Controller with LVGL8 UI and WebGui 
 * on ESP32 Cheap Yellow Display (CYD)
 * 
 * Version 0.5 - 2026-03-17 OE5RNL & OE5NVL
 * 
 * Based on the LVGL8 example from ESP32-Cheap-Yellow-Display
 * https://github.com/witnessmenow/ESP32-Cheap-Yellow-Display)
 * 
 * Hardware: ESP32-2432S028 (CYD) with ILI9341 display and XPT2046 touch
 * Display: 320x240 RGB565
 * Touch: XPT2046 on separate VSPI bus
 */

#include <Arduino.h>
#include <lvgl.h>
#include <TFT_eSPI.h>
#include <XPT2046_Touchscreen.h>
#include <Preferences.h>
#include "version.h"

Preferences prefs;

// ----------------------------
// UI: Tab Menu
// ----------------------------
LV_FONT_DECLARE(lv_font_digits_72);

/* Default: Gesamtmaximum und Maximalwert je Ziffer (0 = Stelle deaktiviert) */
#define DIGIT_MAX_VAL  110   /* maximaler Gesamtwert in dB             */
#define DIGIT_MAX_0      1   /* Hunderter: 0 .. DIGIT_MAX_0           */
#define DIGIT_MAX_1      9   /* Zehner:    0 .. DIGIT_MAX_1           */
#define DIGIT_MAX_2      0   /* Einer:     0 = nicht wählbar          */

#include "webserver.h"

int32_t db_value = 0;
static lv_obj_t * digit_labels[3];  /* 0=hundreds, 1=tens, 2=ones */
static lv_obj_t * digit_cursor;     /* underline indicator */
uint8_t digit_max[3] = { DIGIT_MAX_0, DIGIT_MAX_1, DIGIT_MAX_2 };
int selected_digit = (DIGIT_MAX_2 > 0) ? 2 : (DIGIT_MAX_1 > 0) ? 1 : 0;

/* — Laufzeit-Attenuatorkonfiguration (wird beim Start vom Pico empfangen) — */
static int         att_relay_count = 4;
String             att_name_str    = "";
int32_t            att_step        = 10;
int32_t            att_max_val     = DIGIT_MAX_VAL;
static lv_obj_t * tabview;

/* Default values for the preset buttons (3 x 3) */
int32_t default_values[DEFAULT_BUTTON_COUNT] = {20, 40, 60, 10, 30, 50, 70, 80, 90};
static lv_obj_t * default_labels[DEFAULT_BUTTON_COUNT];

/* Keyboard edit state */
static lv_obj_t * kb = NULL;
static lv_obj_t * ta = NULL;
static int editing_index = -1;
static bool long_press_active = false;
int set_mode = 0;  /* 0=Set-Direct, 1=Set-Time, 2=Set-Button */
bool autoset = true;  /* abgeleitet: true wenn set_mode==0 */
static lv_obj_t * btn_set = NULL;
static lv_obj_t * lbl_set = NULL;
bool              set_pending = false;
static lv_obj_t * ae_btnmatrix = NULL;



/* WiFi mode: 0=off, 2=AP+Client */
uint8_t wifi_mode_setting = 2; /* default: WLAN an */
static lv_obj_t * wifi_switch = NULL;
lv_obj_t * ip_label = NULL;
lv_obj_t * auto_set_label = NULL;  /* Label für AUTO-Set Status */
static lv_obj_t * title_label = NULL;  /* Titel-Label: zeigt ATTNAME */

static lv_obj_t * info_name_label  = NULL;
static lv_obj_t * info_relay_label = NULL;
static lv_obj_t * info_max_label   = NULL;
static lv_obj_t * info_step_label  = NULL;
static lv_obj_t * info_mode_label  = NULL;
static lv_obj_t * version_label    = NULL;  /* ESP-Version */
static lv_obj_t * pico_ver_label   = NULL;  /* Pico-Version */
static String     pico_ver_str     = "";
static lv_obj_t * test_type_label  = NULL;
static int        att_relay_mode   = 0;         /* Testmode: 0=BRIDGE, 1=STATIC */
bool              att_has_rf_switch = false;    /* vom Pico via RFSWITCH: gemeldet */
bool              rf_state          = true;     /* aktueller RF-Schalter-Zustand (gespiegelt vom Pico) */
static lv_obj_t * btn_rf            = NULL;
static lv_obj_t * lbl_rf            = NULL;

/* Remote-Test-UI */
static lv_obj_t * test_controls    = NULL;
static lv_obj_t * test_relay_lbl   = NULL;
static lv_obj_t * test_state_lbl   = NULL;
static lv_obj_t * test_start_btn   = NULL;
static bool       test_active      = false;
static int        test_sel_idx     = 0;
static int        test_count       = 0;
static int        test_states_arr[16] = {};

/* Untermenü-Navigation */
static lv_obj_t * submenu_btn_cont       = NULL;
static lv_obj_t * submenu_pages[4]       = { NULL, NULL, NULL, NULL };
static lv_obj_t * submenu_back_btn       = NULL;

static void send_attenuation_command(bool force_apply)
{
    int32_t att = (db_value / att_step) * att_step;
    if(att > att_max_val) att = att_max_val;
    if(force_apply) {
        Serial.printf("SET:%ddB\n", (int)att);
    }
    else {
        Serial.printf("%ddB\n", (int)att);
    }
}

static void kb_close(void)
{
    if(kb) { lv_obj_del(kb); kb = NULL; }
    if(ta) { lv_obj_del(ta); ta = NULL; }
    editing_index = -1;
}

static void ta_event_cb(lv_event_t * e)
{
    lv_event_code_t code = lv_event_get_code(e);
    if(code == LV_EVENT_READY) {
        const char * txt = lv_textarea_get_text(ta);
        int32_t val = atoi(txt);
        if(val < 0) val = 0;
        if(val > att_max_val) val = att_max_val;  /* Obergrenze */
        /* Gesperrte Stellen auf 0 runden (z.B. Einer gesperrt → 33 → 30) */
        if(digit_max[2] == 0) val = (val / 10) * 10;
        if(digit_max[1] == 0) val = (val / 100) * 100;
        if(editing_index >= 0 && editing_index < DEFAULT_BUTTON_COUNT) {
            default_values[editing_index] = val;
            lv_label_set_text_fmt(default_labels[editing_index], "%d dB", val);
            char key[8];
            snprintf(key, sizeof(key), "def%d", editing_index);
            prefs.putInt(key, val);
            ws_broadcast_def(editing_index);
        }
        kb_close();
        update_config_value(val);
        ws_broadcast_val();
    }
    else if(code == LV_EVENT_CANCEL) {
        kb_close();
    }
}

static void btn_long_press_cb(lv_event_t * e)
{
    long_press_active = true;
    int idx = (int)(intptr_t)lv_event_get_user_data(e);
    editing_index = idx;

    lv_obj_t * btn = lv_event_get_target(e);
    lv_area_t btn_area;
    lv_obj_get_coords(btn, &btn_area);

    ta = lv_textarea_create(lv_scr_act());
    lv_textarea_set_one_line(ta, true);
    lv_textarea_set_max_length(ta, 3);
    lv_obj_set_width(ta, lv_obj_get_width(btn));
    lv_obj_set_height(ta, lv_obj_get_height(btn));
    lv_obj_set_pos(ta, btn_area.x1, btn_area.y1);
    char val_buf[8];
    snprintf(val_buf, sizeof(val_buf), "%d", (int)default_values[idx]);
    lv_textarea_set_text(ta, val_buf);
    lv_obj_add_event_cb(ta, ta_event_cb, LV_EVENT_READY, NULL);
    lv_obj_add_event_cb(ta, ta_event_cb, LV_EVENT_CANCEL, NULL);

    kb = lv_keyboard_create(lv_scr_act());
    lv_keyboard_set_mode(kb, LV_KEYBOARD_MODE_NUMBER);
    lv_keyboard_set_textarea(kb, ta);
    if(idx >= 6) {
        lv_obj_set_size(kb, lv_pct(100), 120);
        lv_obj_align(kb, LV_ALIGN_TOP_MID, 0, 0);
    }

    lv_obj_add_state(ta, LV_STATE_FOCUSED);
    lv_obj_clear_state(ta, LV_STATE_FOCUS_KEY);
}

/* Update the 3 digit labels from db_value */
static void update_digit_labels(void)
{
    int v = db_value;
    char d[2] = {0, 0};
    d[0] = '0' + (v / 100) % 10;
    lv_label_set_text(digit_labels[0], d);
    d[0] = '0' + (v / 10) % 10;
    lv_label_set_text(digit_labels[1], d);
    d[0] = '0' + v % 10;
    lv_label_set_text(digit_labels[2], d);
}
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

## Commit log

2026-03-15 Initial commit: LVGL8 Widget Demo for ESP32 CYD
2026-03-15 Board Doku
2026-03-16 AP, Client und wlan aus implementiert
2026-03-16 default auf web und display setzten
2026-03-16 editfeld beim logCloick auf eine der drei Ziffern
2026-03-16 flacker der 3 Ziffern im Webentfernt
2026-03-21 esp32 und pico version parallel
2026-03-21 pico minimal -> blinpy
2026-03-21 serial esp <-> pico
2026-03-21 pico display vorbereitet
2026-03-21 pico vorbereitet für mehrere abschwächer
2026-04-08 AP und SSID Text in config
2026-04-09 verzögertes schalten der relais bei ap only mode behoben
    [main.cpp]
2026-04-11 135db Schaltung
    [RP-006426-DD-A-Raspberry Pi Pico 2 3D CAD Model R5 24 07 24.step, att.kicad_pcb, att.kicad_sch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]
2026-04-17 schaltung PCB
    [att.kicad_pcb, att.kicad_sch]
2026-04-19 .gitignore Schaltung
    [att.kicad_pcb, att.kicad_sch]
2026-04-19 R umbenannt. div bereinigungen
    [att.kicad_pcb, att.kicad_sch]
2026-04-19 Bridge Labels+Trenner
    [att.kicad_pcb]
2026-04-19 Schaltung new 1
    [1-Body.step, 1.FCStd, RP-006426-DD-A-Raspberry Pi Pico 2 3D CAD Model R5 24 07 24.step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]
2026-04-19 vor 26.5 ghz buchse ändern
    [att.kicad_pcb]
2026-04-20 final vor nvl check
    [att-B_Cu.gbl, att-B_Mask.gbs, att-B_Paste.gbp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]
2026-04-20 Stückliste
    [att.csv, att.kicad_sch, att.ods]
2026-04-20 att select
    [att-B_Cu.gbl, att-B_Mask.gbs, att-B_Paste.gbp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]
2026-04-21 vor produktion 1
    [1-Body.step, 1.FCStd, RP-006426-DD-A-Raspberry Pi Pico 2 3D CAD Model R5 24 07 24.step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]
2026-05-05 Version 1.1 der Schaltung
    [1-Body.step, 1.FCStd, RP-006426-DD-A-Raspberry Pi Pico 2 3D CAD Model R5 24 07 24.step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]
2026-06-01 pico menü
2026-06-05 switch persistentz
2026-06-06 button-set info auf deb Displays
2026-06-06 set-mode "set-button" hinweise auf esp,pico und web
2026-06-07 Versionsausgabe über uart an konsole
